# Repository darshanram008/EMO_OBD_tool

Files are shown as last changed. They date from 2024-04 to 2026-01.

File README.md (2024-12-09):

# On board diagnostic tool: developed for EMO energy pvt ltd. 
## On Board diagnostic tool is a simple PCB that can be interfaced with the internal battery management system that cannot be accessed during the maintence or diagnostics of the battery pack 

<!--Table  of contents
- [section 1](#section-1)
- [section 2](#section-2)-->

*The priamry functionn of the OBD tool:*
1. Communicate via controller area network (CAN) protocol to the battery and
request the BMS to send necessary data.
2. Communicate via the Universal serial asynchronous RX-TX protocol to the GUI
and deliver the data in human readable from.

*The following operations are implemenetd*
1. Request real time data containing cell voltages, pack voltage, pack current,
temperatures, error and faults from the BMS and transmit to the USB via UART
in the form of strings appended with certain identifiers.
2. Request the configuration parameters from the BMS that was already uploaded
upon getting a command request from the GUI
3. Push the new configuration parameters to the BMS on command request from the
GUI.
4. Request SD card data to be downloaded on request from the GUI.
5. Change baud rates of UART and CAN upon command request from GUI
6. Flow control between OBD and BMS whenever there is an event of exchanging
data.

## 
- Microcontroller unit: Microchip PIC18F27Q84
- CAN transciever: Microchip MCP2551; variable Baud rate upto 1Mbps
- UART to USB converter: Silicon labs CP2102; variable baud rate uptp 115200
- Micrchip MPLAB X IDE

<!-- > some block quote itseems -->

<!-- `this is where code comes` -->

----------------
<!--
[We can post any link if you want] (https://github.com/darshanram008/EMO_OBD_tool/edit/main/README.md)

![This is how the PCB looks](EMO_PCB_IMG.png)

This is a footnote, you press this it will take you to the footnote. [^1]
Note: Footnotes are always at the end of this file.
## SECTION 1
> This is table

| Left side | Right side |
|---|---|
| 1. The advantage is good | 1. The advantage is bad |
| 2. The advantage is good | 2. The advantage is bad |
| 3. The advantage is good | 3. The advantage is bad |
| 4. The advantage is good | 4. The advantage is bad |

```
{
   \\This is fenced code 
  if (count == 0)
  {
  printf("Hello, zeros"):  
  }

}
```
## SECTION 2
> Definitions

UART
: Universal Asyncronous receiver and transmitter

CAN
: Controller area network

~~Strikeout anything~~

- [x] Task completed
- [x] Task completed
- [ ] Task Incomplete
- [ ] Task incomplete

There are emoji as well! :joy:

i have more :angry:

take more 📶

==Some very important points==.

to put subscript you can do this H<sub>2</sub>O

To put superscript do this X<sup>2</sup>Y

[^1]: This is the footnote, you can add any references you want.

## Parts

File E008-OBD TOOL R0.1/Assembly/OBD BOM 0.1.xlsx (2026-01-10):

Sl.No | Reference | Value | Footprint | Description | MPN | Manufacturer | Qty
1 | C1-C3, C9, C12 | 4.7uF/25V | Capacitor_SMD:C_0402_1005Metric | 402 | CC0402MRX5R7BB475 | YAGEO | 5
2 | C4 | 1uF/25V | Capacitor_SMD:C_0402_1005Metric | 402 | CC0402KPX5R7BB105 | YAGEO | 1
3 | C5 | 0.1n/25V | Capacitor_SMD:C_0402_1005Metric | 402 | CC0402KRX7R7BB101 | YAGEO | 1
4 | C6, C7 | 33p/25V | Capacitor_SMD:C_0402_1005Metric | 402 | CC0201JPNPO7BN330 | YAGEO | 2
5 | C8, C10, C11 | 0.1uF/25V | Capacitor_SMD:C_0402_1005Metric | 402 | CC0402KRX7R7BB104 | YAGEO | 3
6 | C13 | 0.001uF/25V | Capacitor_SMD:C_0402_1005Metric | 402 | CC0100KRX7R7BB102 | YAGEO | 1
7 | C14 | 0.01uF/25V | Capacitor_SMD:C_0402_1005Metric | 402 | CC0805JKNPO7BN103 | YAGEO | 1
8 | D1 | SP0505BAHT | Custommm:SP0505BAHT_SOT95P280X145-6N.kicad_mod |  | SP0505BAHTG |  | 1
9 | D2, D4 | LED | LED_THT:LED_D3.0mm_IRBlack | LED |  | bivar | 2
10 | D3 | LED | LED_SMD:LED_0603_1608Metric | LED |  | bivar | 1
11 | H1-H6 | MountingHole | MountingHole:MountingHole_2.2mm_M2 |  |  |  | 6
12 | J1 | samtec_03x02 | Custommm:SAMTEC_1.27mm_03x02 | DEBUG |  |  | 1
13 | J2 | I2C | Connector_PinHeader_1.27mm:PinHeader_1x04_P1.27mm_Vertical | 4 pin JST connector | 240-004 | Digilent | 1
14 | J4 | USB C 2.0 | Connector_USB:USB_C_Receptacle_HRO_TYPE-C-31-M-12 | USB C | USB4105-GF-A | GCT | 1
15 | J6 | CAN | Connector_JST:JST_GH_SM03B-GHS-TB_1x03-1MP_P1.25mm_Horizontal |  | SM03B-GHS-TB |  | 1
16 | JP1 | Jumper_2_Open | Jumper:SolderJumper-2_P1.3mm_Open_RoundedPad1.0x1.5mm |  |  |  | 1
17 | R1-R3, R5, R7, R20, R25, R26, R35 | 0R | Resistor_SMD:R_0603_1608Metric | 603 | RC0603FR-SNE96L | YAGEO | 9
18 | R4 | 120R | Resistor_SMD:R_0402_1005Metric | 402 | RC0402FR-07120RL | YAGEO | 1
19 | R6, R8, R12, R17, R22-R24 | 1k | Resistor_SMD:R_0402_1005Metric | 402 | RT0402BRE071KL | YAGEO | 7
20 | R9, R41, R42 | 330R | Resistor_SMD:R_0402_1005Metric | 402 | RC0402JR-7D330RL | YAGEO | 3
21 | R10 | 10k | Resistor_SMD:R_0402_1005Metric | 402 | RC0402FR-0710KL | YAGEO | 1
22 | R11 | 470R | Resistor_SMD:R_0402_1005Metric | 402 | RC0402FR-07470RL | YAGEO | 1
23 | R13, R14 | 5.1k | Resistor_SMD:R_0402_1005Metric | 402 | RC0402FR-075K1L | YAGEO | 2
24 | R15 | 0R | Resistor_SMD:R_0805_2012Metric | 603 | RC0603FR-SNE96L | YAGEO | 1
25 | R16 | 5A fuse | Custommm:FUSE | - | 0494.250NR | YAGEO | 1
26 | R18 | 22.1k | Resistor_SMD:R_0402_1005Metric | 402 | RC0402FR-1322K1L | YAGEO | 1
27 | R19 | 47.5k | Resistor_SMD:R_0402_1005Metric | 402 | RC0402FR-0747K5L | YAGEO | 1
28 | R21, R38-R40 | 10K | Resistor_SMD:R_0402_1005Metric | 402 | RC0402FR-0710KL | YAGEO | 4
29 | R27, R28 | 10R | Resistor_SMD:R_0603_1608Metric | 603 | RC0603FR-0710RL | YAGEO | 2
30 | R29-R34, R36, R37 | 1k | Resistor_SMD:R_0603_1608Metric | 603 | RT0603WRE071KL | YAGEO | 8
31 | U1 | PIC18F27Q84 | Custommm:PIC18F27Q84_SOIC127P1030X265-28N | MCU | PIC18F27Q84-E/SO | Microchip Technology | 1
32 | U2 | MCP2551-I-P | mcp2551:SOIC127P600X175-8N | CAN IC | MCP2551-I/SN | Microchip Technology | 1
33 | U3 | CP2102-GMR | Custommm:QFN50P500X500X100-29N-D | UART to USB | 634-CP2102-GMR |  | 1
34 | U4 | AT24C256C-SSHL-T | Custommm:AT24C256_SOIC127P600X175-8N | EEPROM | AT24C256C-SSHL-T |  | 1
35 | Y2 | 10MHz | Custommm:ABLS8000MHZB4T | CRYSTAL | ABM7-10.000MHZ-D2Y-T | ABRACON | 1

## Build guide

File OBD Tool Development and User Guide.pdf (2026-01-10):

## OBD Tool Development and User Guide

## August 2023

The following document summarises the initiation and development of a general On-Board diagnostic tool over the course of Feb 2023 to August 2023 for all the battery packs and energy storage systems developed by EMO energy Pvt. ltd.

INTRODUCTION

The On-Board diagnostic tool is the mediator between the graphical user interface (GUI) and the battery management system (BMS) allowing data to be communicated seamlessly by converting data from BMS readable format to human readable format and vice versa.

The primary functions of the OBD tool are as follows
1. Communicate via controller area network (CAN) protocol to the battery and request the BMS to send necessary data.
2. Communicate via the Universal serial asynchronous RX-TX protocol to the GUI and deliver the data in human readable from.

At present the following functions have been implemented:

1. Request real time data containing cell voltages, pack voltage, pack current, temperatures, error and faults from the BMS and transmit to the USB via UART in the form of strings appended with certain identifiers.
2. Request the configuration parameters from the BMS that was already uploaded upon getting a command request from the GUI
3. Push the new configuration parameters to the BMS on command request from the GUI.
4. Request SD card data to be downloaded on request from the GUI.
5. Change baud rates of UART and CAN upon command request from GUI
6. Flow control between OBD and BMS whenever there is an event of exchanging data.

## CHAPTER 1

## HARDWARE DESIGN

1. The PCB for the OBD tool is designed in KICAD
2. PIC18F27Q84 is used as the MCU on the PCB (Note: The available curiosity nano development board has PIC18F57Q84 as its MCU)
3. CP2102-GMR QFN29 is used for UART to USB converter, MCP2551 is used as CAN controller.
4. USB C is used for connecting it to the device running GUI, and a 3 pin JST connector is used for connecting to the BMS.
5. A 10MHz crystal is used for as external clock for the PIC.

Further schematics and layout can be found in the KICAD project.

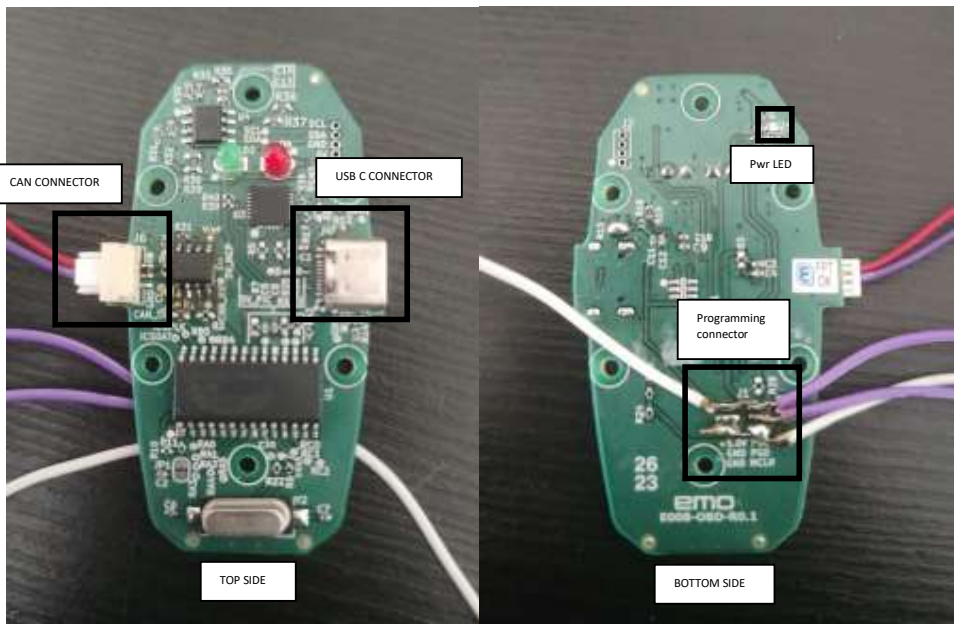
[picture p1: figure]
CAN CONNECTOR; USB C CONNECTOR; Programming connector; Pwr LED; TOP SIDE; BOTTOM SIDE

## CHAPTER 2

## FIRMWARE DEVELOPMENT

The OBD is made sure to be useable only when the GUI is opened on the host computer as a result a simple state machine consisting of two states is implemented.

- “GUI_connected” state
- “GUI_disconnected” state
1. GUI_disconnected state

This state is when the OBD is powered and the GUI application is not opened on the host computer.

- The OBD sends command “AT+TEST\r\n” continuously on the UART until it receives command “AT+TEST+OK\r\n”
- During disconnected state any normal operation or sending commands through foreign serial terminal is prohibited, unless it is a “AT+TEST=OK\r\n” command which is a breach of security.
- Upon reading “AT+TEST=OK\r\n” the OBD switches to the next state.
2. GUI_connected state

This state is when the OBD is powered and the GUI application is running on the host computer

- There are 10 events that the OBD might go into during this state
- Default_event: To continuously request BMS the data containing pack voltage, pack current, SOC and error codes followed by 20 cell voltages and 6 thermistor values. The data is appended to three strings. First containing error codes, pack voltage, pack current and SOC with “VCS” as identifiers, Second containing the 20 cell voltages with “#*” as identifiers, third containing 6 thermistor values with “^C” as identifier. All three strings are sent over UART continuously as comma separated values.
CAN ID for request: 0x1806F4F4
CAN DATA for request: {0x04, 0x0D, 0x04, 0x63}
- BMS_baud_rate_change_event & GUI_baud_rate_change_event: Request to change the baud rates/ bit rates of the CAN for the BMS or the UART for the GUI.
The request to change the baud rate is initiated by the GUI through the following commands
For UART:
1. “AT+BAUD=1\r\n”: Changes UART baud rate to 9600 (default) when OBD is powered or reset.
2. “AT+BAUD=2\r\n”: Changes UART baud rate to 57600
3. “AT+BAUD=3”: Changes UART baud rate to 115200

For CAN:

1. “AT+CANB=1\r\n”: Changes CAN bit rate to 125Kbps
2. “AT+CANB=2\r\n”: Changes CAN bit rate to 250Kbps
3. “AT+CANB=3\r\n”: Changes CAN bit rate to 500Kbps

Note: The default CAN bit rate when OBD is powered will go to 250Kbps, however when changed by the GUI the OBD will register the new bit rate to its EEPROM. Upon changing the bit rate of the OBD a message is also sent to the BMS on the older baud rate to change its bit rate to the new bit rate that OBD has been asked to set to.

CAN ID for 125Kbps: 0x1806F4F4; CAN DATA: {0x04, 0x0D, 0x04, 0x66}

CAN ID for 250Kbps: 0x1806F4F4; CAN DATA: {0x04, 0x0D, 0x04, 0x65}

CAN ID for 500Kbps: 0x1806F4F4; CAN DATA: {0x04, 0x0D, 0x04, 0x64}

- sd_data_download_event: Request to download the SD card data from given set of from date and to date. The request to download the SD card data from the BMS is
initiated | by | the | GUI | with | the | command:
“AT+DATA=1,DD,MM,YY,DD,MM,YY\r\n” (from date followed by To date) or “AT+DATA=2\r\n” if the entire SD card data has to be downloaded.
On receiving the command, the dates are segregated and stored in an 8byte array, the first two bytes will contain the character ‘S’ and ‘D’ the remaining 6 bytes will contain the DD MM YY DD MM YY.
CAN ID for DATE download: 0x1806F4F4; CAN DATA: {‘S’, ‘D’, DD,MM,YY,DD,MM,YY}
CAN ID for FULL download: 0x1806F4F4; CAN DATA: {‘S’, ‘D’, 0xFF, 0xFF, 0x00, 0x00, 0x00, 0x00}

Flow control for exchanging SD card data:

The flow control is written in such a way that after exchanging 48bytes (1 packet) between the OBD and the BMS, it is sent to the GUI with “SD” as identifiers with every byte as comma separated values.

1 packet (48bytes) consists of 7 CAN frames/messages with ID: 0x0121FFF4
Frame 1: {0x10,D1,D2,D3,D4,D5,D6,D7}
D1: contains the number of bytes in a packet, for examples if first packet has 48bytes D1 would be 48, if last pack has just 46bytes then D1 would be 46 and so on.
Frame 2: {0x20,D1,D2,D3,D4,D5,D6,D7}
Frame 3: {0x21,D1,D2,D3,D4,D5,D6,D7}
Frame 4: {0x22,D1,D2,D3,D4,D5,D6,D7}
Frame 5: {0x23,D1,D2,D3,D4,D5,D6,D7} Frame 6: {0x24,D1,D2,D3,D4,D5,D6,D7}
Frame 7: {0x25,D1,D2,D3,D4,D5,D6,D7}

Upon sending the request for downloading SD card data to the BMS, the BMS responds with the Frame 1, then OBD responds back with an acknowledgement
message | with | ID | 0x1806F4F6 | and | data
{0x01,0x00,0x00,0x00,0x00,0x00,0x00,0x00} it then starts its timer and waits for the next frame, if the BMS does not respond within 6sec (set by the timer) OBD transmits a timeout message to both BMS and GUI and goes back to the default event.

BMS timeout message: ID: 0x1806F4F6 data: {0xFF,0xFF,0x00,0x00,0x00,0x00,0x00,0x00}
GUI timeout message: “AT+TIME\r\n”

If the BMS responds within 6 seconds the OBD continues to wait for subsequent frames and after the reception of all the 7 frames (48bytes) (1 packet), the BMS sends
a | confirmation | message | on | the | ID: | 0x0110FFF4 | with | the | data
{0x01,0x00,0x00,0x00,0x00,0x00,0x00,0x00}. and the OBD sends the received packet to the GUI as a CSV string with “SD” appended on it. The BMS Upon sending all the packets of the SD card data sends a “complete” message on the ID: 0x0110FFF4 with data: {0x02,0x00,0x00,0x00,0x00,0x00,0x00,0x00}. And the OBD sends the last packet to the GUI followed by a confirmation message “AT+DONE\r\n”.
- BMS_software_rst_event:

The request for resetting the BMS is initiated by the GUI with the command “AT+REST=1\r\n”

Upon receiving the command the OBD forwards the command request to the BMS through the ID:0x1806F4F5 with the message {0x00,0xFF,0x01,0x00}. The BMS if reset sends a confirmation message to the OBD on the ID: 0x0110FFF4 with the message{0x01,0x00,0x00,0x00,0x00,0x00,0x00}
The OBD on receiving this command sends a confirmation message to the GUI
“AT+DONE\r\n” | indicating | the | successful | resetting | of | the | BMS.
If the BMS fails to respond with the confirmation message within 6 sec (set by the timer) the OBD sends a timeout message to BMS and GUI and goes back to its default event.
BMS timeout message: ID: 0x1806F4F6 data: {0xFF,0xFF,0x00,0x00,0x00,0x00,0x00,0x00}
GUI timeout message: “AT+TIME\r\n”
- BMS_upl_config_event:

The process for uploading the new configuration parameters to the BMS is initiated by the GUI with the command “AT+CONF=1,xxxx,xxxx,xxxx,xxxx,xxxx,xxxx,xxxx,xx,xx,xx,xx,xx,xx,xx,xx\r\n” Where x represents digits, currently 15 parameters have been finalised. The parameters that contain 2 bytes of data has to be put in place of 4 digits and the parameters containing 1 byte data has to be put in place of 2 digits.
It is important to note that the parameters have to be sent in the form of 4 or 2 digits as OBD string processing is strictly based on the length of the string.
Since there are 15 parameters in total, 7 parameters with 2 bytes (4 digit) 8 parameters with 1 byte(2digit) there are totally 22 bytes of data to be transmitted to BMS.
The transmission is on the ID: 0x1806F4F5 with frames as follows.

Frame 1: {0x01, LSB1,MSB1,LSB2,MSB2,LSB3,MSB3,1

st two-digit }
Frame 2: {0x02, LSB4,MSB4,LSB5,MSB5,LSB6,MSB6,2

nd two-digit]}
Frame 3: {0x03, LSB7,MSB7, 3

rd two-digit,4

th two-digit ,5

th two-digit ,6

th
two-digit }
Frame 4: {0x04, 7

th two-digit, 8

th two-digit,0x00,0x00,0x00,0x00,0x00]} After each frame transmitted, the OBD waits for a confirmation message from the
BMS | that | comes | on | the | ID: | 0x0110FFF4 | with | the | data
{0x01,0x00,0x00,0x00,0x00,0x00,0x00,0x00}, if the confirmation is not received by the OBD within 6 seconds (set by the timer) it simply sends a timeout message to BMS and GUI and goes back to the default event.
BMS timeout message: ID: 0x1806F4F6 data: {0xFF,0xFF,0x00,0x00,0x00,0x00,0x00,0x00}
GUI timeout message: “AT+TIME\r\n”

After the last frame has been sent and confirmed by the BMS, the OBD sends a confirmation message to the GUI “AT+DONE\r\n”

- BMS_get_config_event:

The request to get the present configuration parameters from the BMS is initiated by the GUI with the command “AT+CONF=2\r\n”

The OBD upon receiving the command sends a request message to the BMS with the ID: 0x1806F4F5 and data: {0x00,0x01,0x00,0x00} and waits for the BMS to respond with a CAN message containing the ID:0x0121FFF5 and the following frames
Frame1: {0x01,LSB1,MSB1,LSB2,MSB2,LSB3,MSB3,1
| | | | | | st two-digit}
Frame2: {0x02,LSB4,MSB4,LSB5,MSB5,LSB6,MSB6,2

nd two-digit}
Frame3: {0x03,LSB7,MSB7,3

rd two-digit,4

th two-digit,5

th two-digit,6

th two-digit,7

| | | | | | | | | th two-
digit}
Frame4: {0x04,8

th two-digit,0x00,0x00,0x00,0x00,0x00,0x00}

After every frame is received from the BMS the OBD sends a confirmation on the ID: 0x1806F4F6 with the data: {0x01,0x00,0x00,0x00,0x00,0x00,0x00,0x00} and waits for the next frames to receive, if the time elapsed in waiting exceeds 6sec the OBD sends a timeout message to BMS and GUI and then goes back to the default event.

After the last frame has been sent by the BMS it sends a “complete” message on the ID: “0x0110FFF4” with the data {0x02,0x00,0x00,0x00,0x00,0x00,0x00,0x00}, After which the OBD sends the parameters to GUI as CSV string with “CON” as identifiers.

- BMS_bootloader_event:

Refer the following excel for the detailed CAN messages. CAN data - Google Sheets (https://docs.google.com/spreadsheets/d/1CL77GdZRY7Kqr-tseltxFlh5MpObE5scavTE46g4DnU/edit#gid=0)

## CHAPTER 3

## MPLAB CODE CONFIGURATION

The entire firmware is developed in MPLAB X IDE v6.10.

The projects titled OBD_CAN_UART is written for curiosity nano board carrying PIC18F57Q84 MCU, and the project titled OBD_TOO_PCB_FINAL is written for the E008-PCB carrying PIC18F27Q84 MCU.

The steps to configure projects for the development is as shown:

1. Create a new project from the file section, select standalone project and click next, choose the device as PIC18F27Q84 and click next, select xc8 compiler and give the project name and click finish.

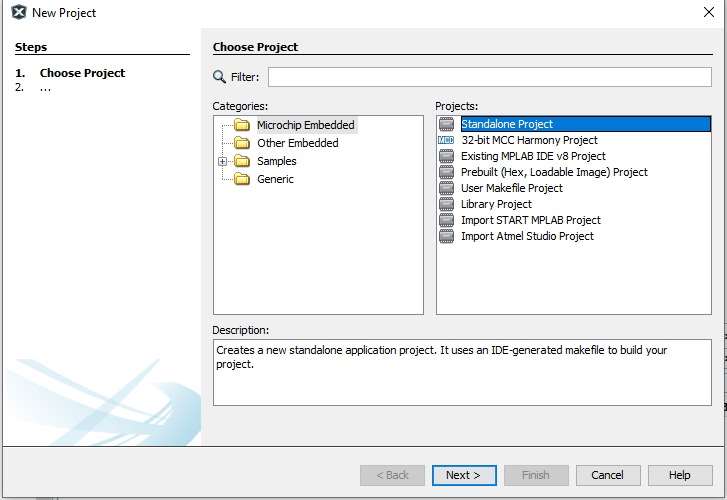
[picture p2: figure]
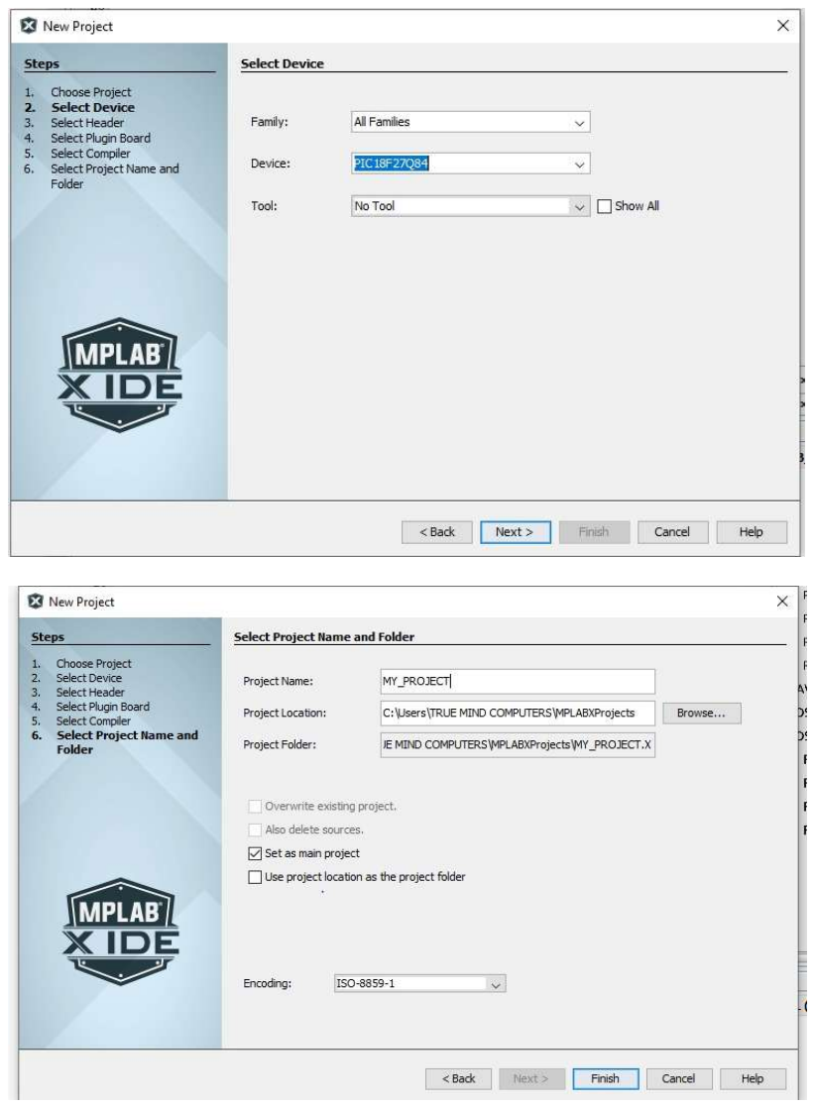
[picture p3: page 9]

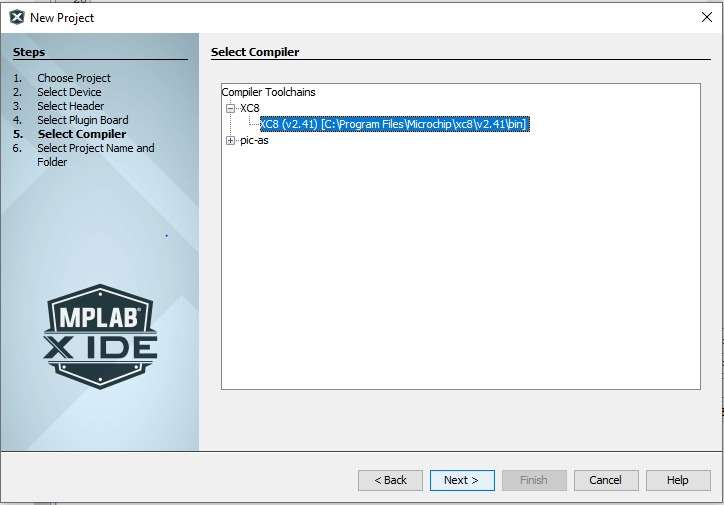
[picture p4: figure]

2. Open the MPLAB code configurator by clicking the blue logo called the MCC from the main page.

3. Select MCC classic.

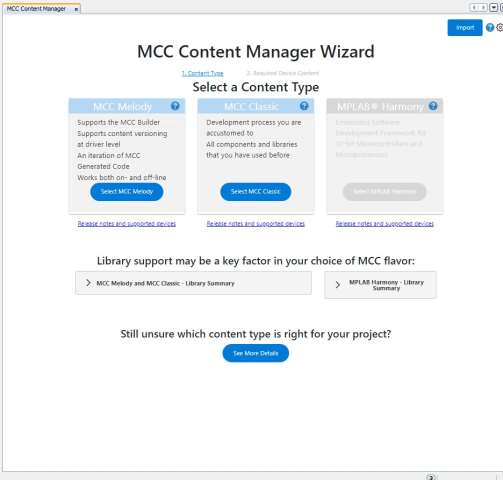
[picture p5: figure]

4. After downloading necessary modules click on finish

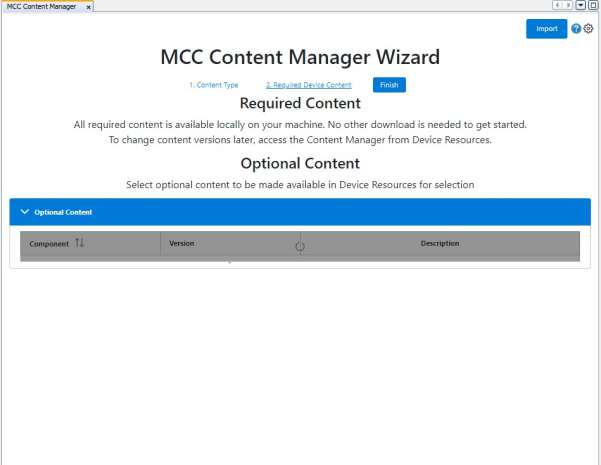
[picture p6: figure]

5. In the peripherals section click on plus to add the following peripherals UART2, CAN1, TIMER0, TIMER2, MEMORY

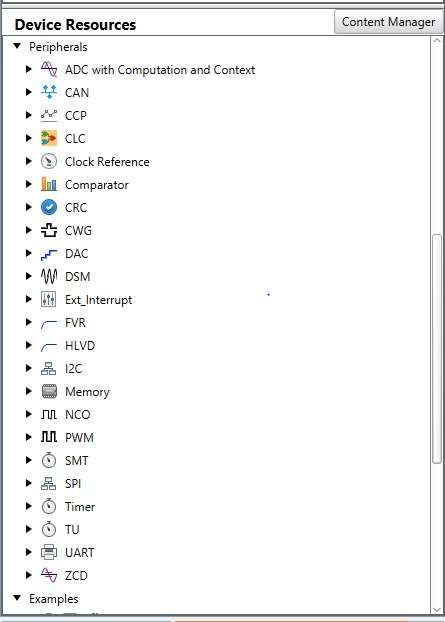
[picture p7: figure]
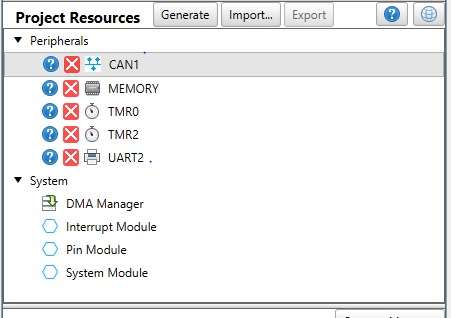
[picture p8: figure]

6. In the system module tab configure the following

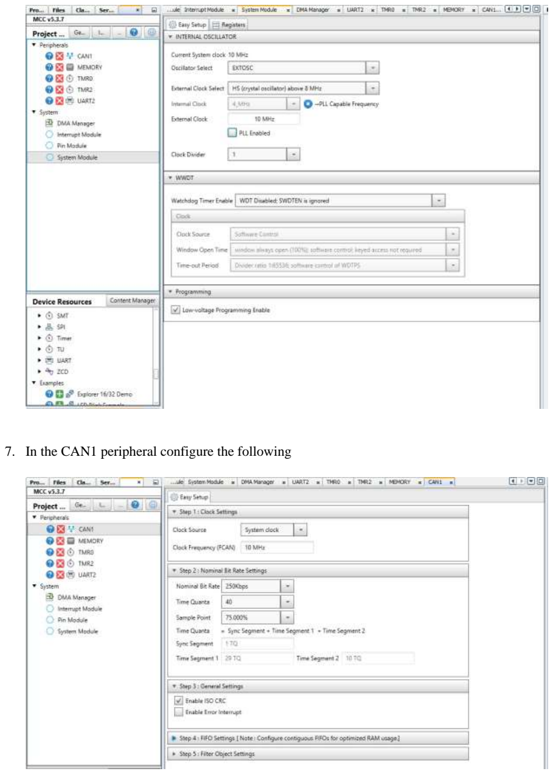
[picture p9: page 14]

7. In the CAN1 peripheral configure the following

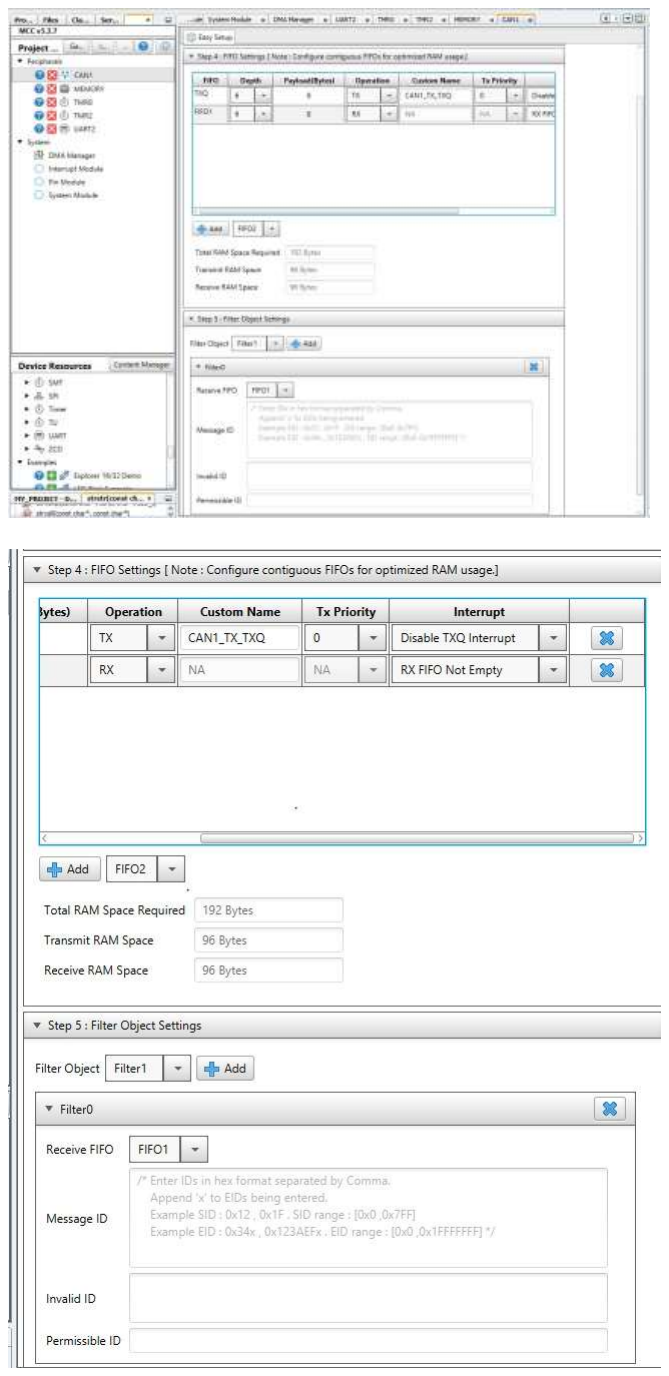
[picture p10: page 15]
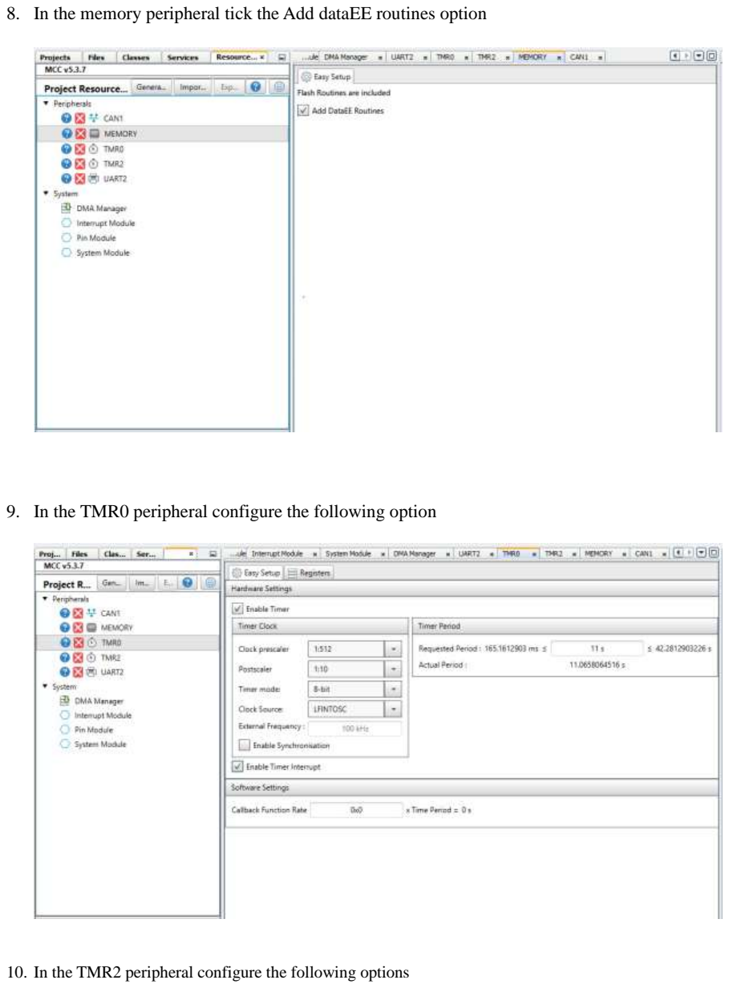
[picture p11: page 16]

8. In the memory peripheral tick the Add dataEE routines option
9. In the TMR0 peripheral configure the following option
10. In the TMR2 peripheral configure the following options

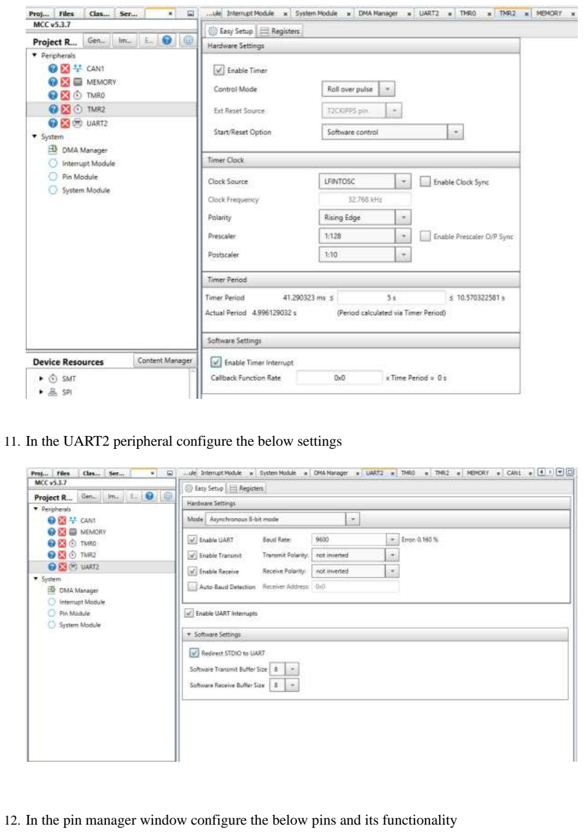
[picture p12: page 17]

11. In the UART2 peripheral configure the below settings
12. In the pin manager window configure the below pins and its functionality

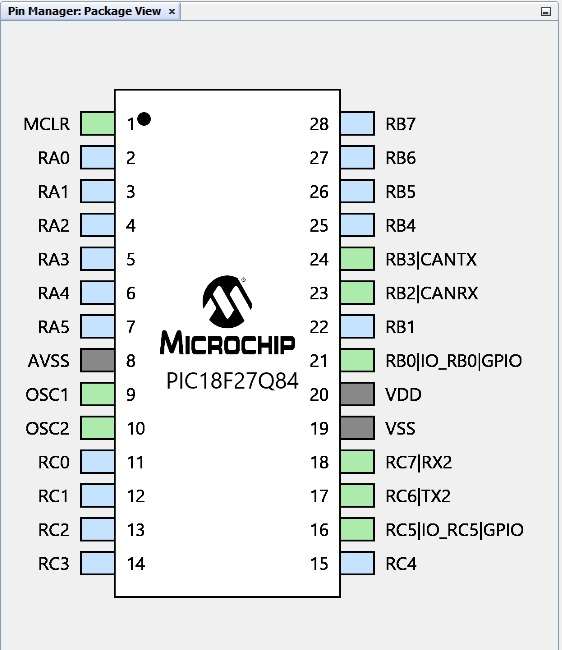
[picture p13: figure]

13. Make sure the following are enabled in interrupt module window

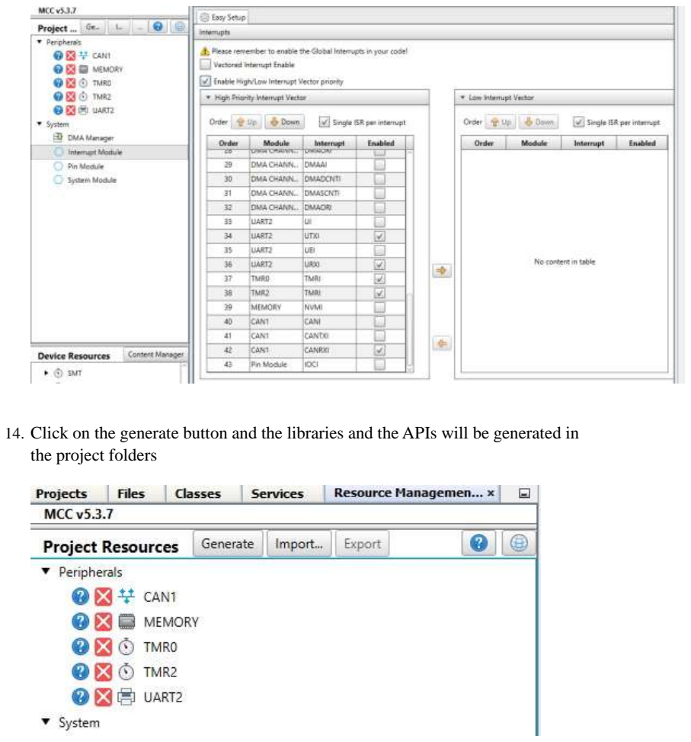
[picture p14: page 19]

14. Click on the generate button and the libraries and the APIs will be generated in the project folders

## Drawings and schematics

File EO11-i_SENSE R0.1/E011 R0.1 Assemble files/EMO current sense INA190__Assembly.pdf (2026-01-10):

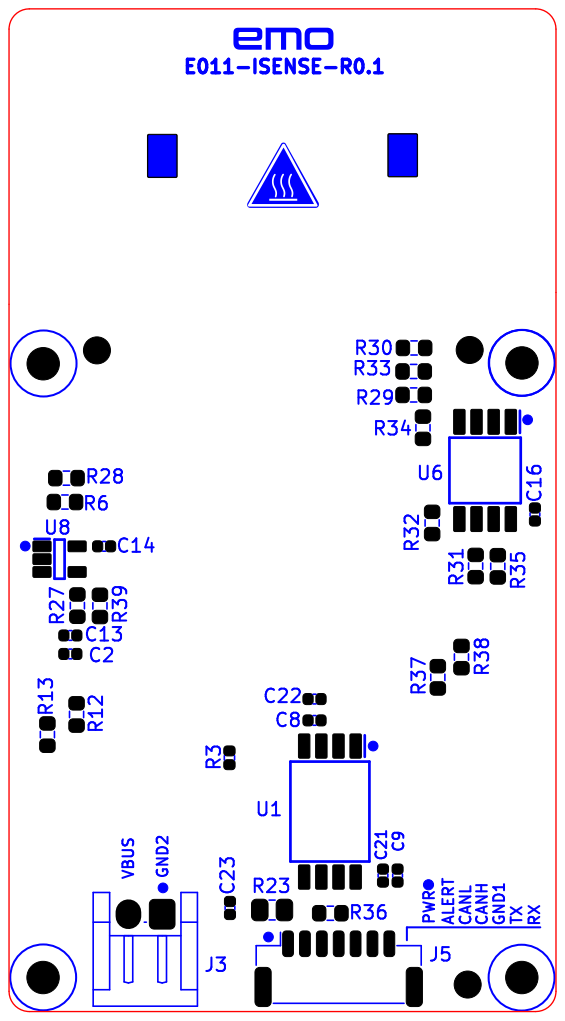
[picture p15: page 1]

GND2 TXRX E011-ISENSE-R0.1 VBUS PWR ALERT CANL CANH GND1 R13 C8 C16 R37R38 U6

J2 U2 CANL R¹⁶ | RA4C⁷ R⁷ U5 | C⁴

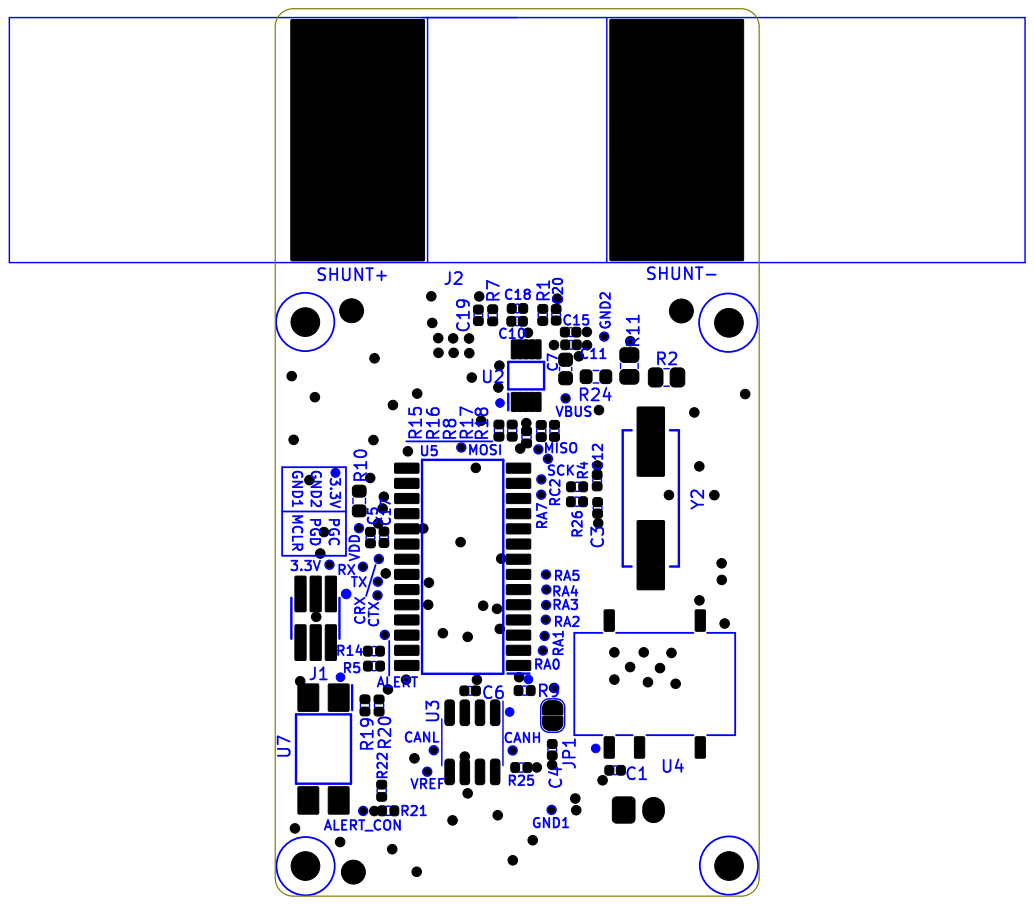
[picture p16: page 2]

GND1 3.3V SHUNT+ MCLR PGD PGC SHUNT- GND2 R20 R15 C5 R1 C20 VBUS R8

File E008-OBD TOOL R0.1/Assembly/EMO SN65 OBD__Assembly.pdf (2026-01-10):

C13 | U¹ CAN_RX | R36 U3 | SBU1 RA⁴ | R22 RA1 R1 | D2 | TX R¹⁷ cin
R4 | R¹⁶ RXR37 cout | J4 R29 | R³⁸

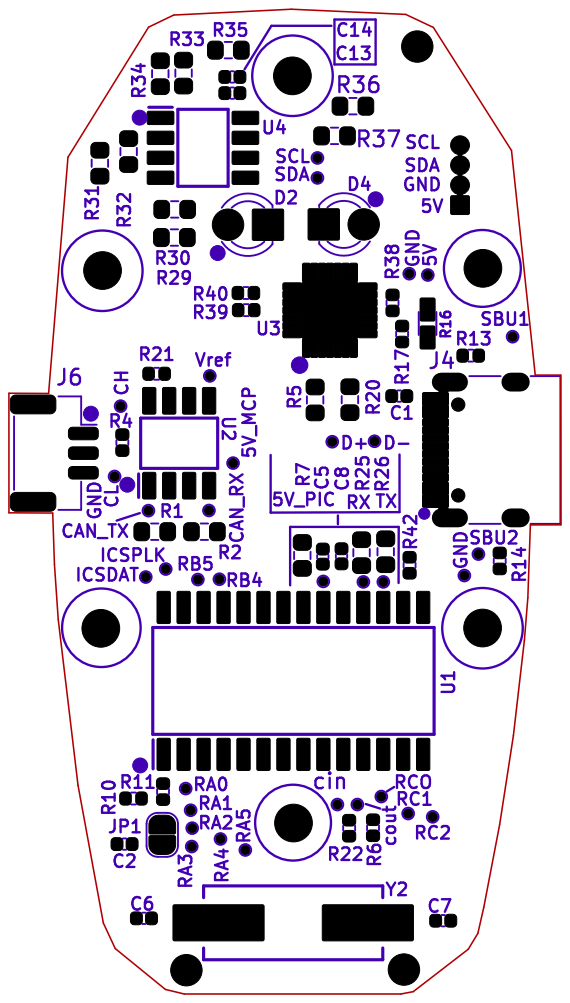
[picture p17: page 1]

+5.0V PGC GND PGD MCLR R²⁴ | C10 R²³ | R8 R⁴¹ | C3R12 J2 R¹⁹ E008-OBD-R0.1 | D³ C¹² | R²⁷ R³ R¹⁵ | R²⁸ C¹¹ | D1 R¹⁸ | J1 R⁹ C4 C9

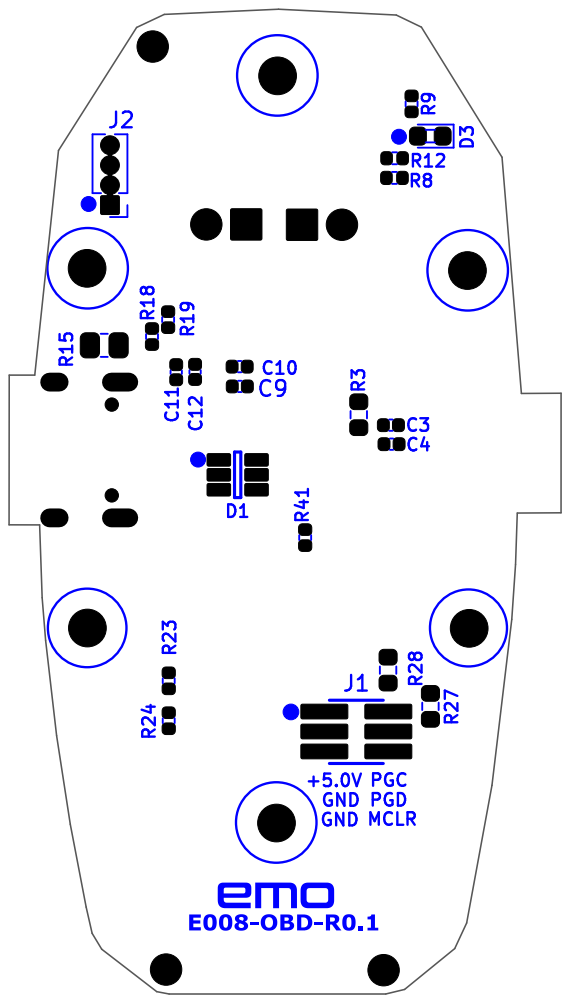
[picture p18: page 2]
GND

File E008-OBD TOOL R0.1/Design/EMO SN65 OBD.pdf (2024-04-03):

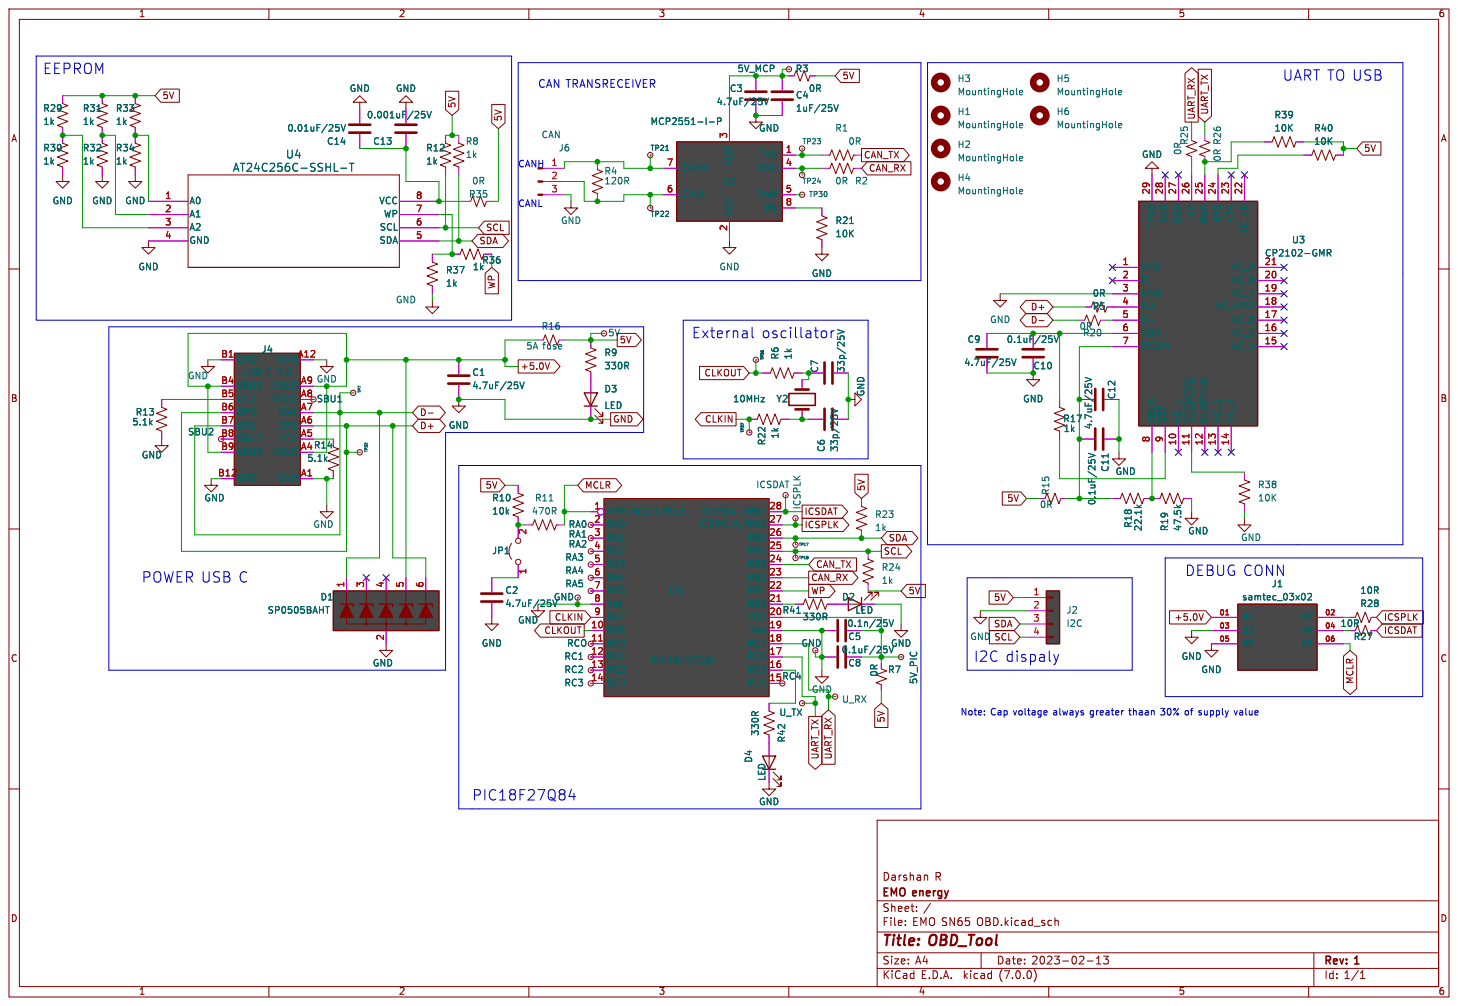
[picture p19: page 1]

3 RXD 4 Vref 5 CANL 6 CANH 7 Rs 8 U2 MCP2551-I-P

3 RXD 4 Vref 5 CANL 6 CANH 7 Rs 8

TP22 GNDA12 GND A1 VBUS A4 CC1 A5 DP1 A6 DN1 A7 SBU1 A8 VBUS A9 GND B1 GND B12 VBUS B4 CC2 B5 DP2 B6 DN2 B7 SBU2 B8 VBUS B9

Note: Cap voltage always greater thaan 30% of supply value

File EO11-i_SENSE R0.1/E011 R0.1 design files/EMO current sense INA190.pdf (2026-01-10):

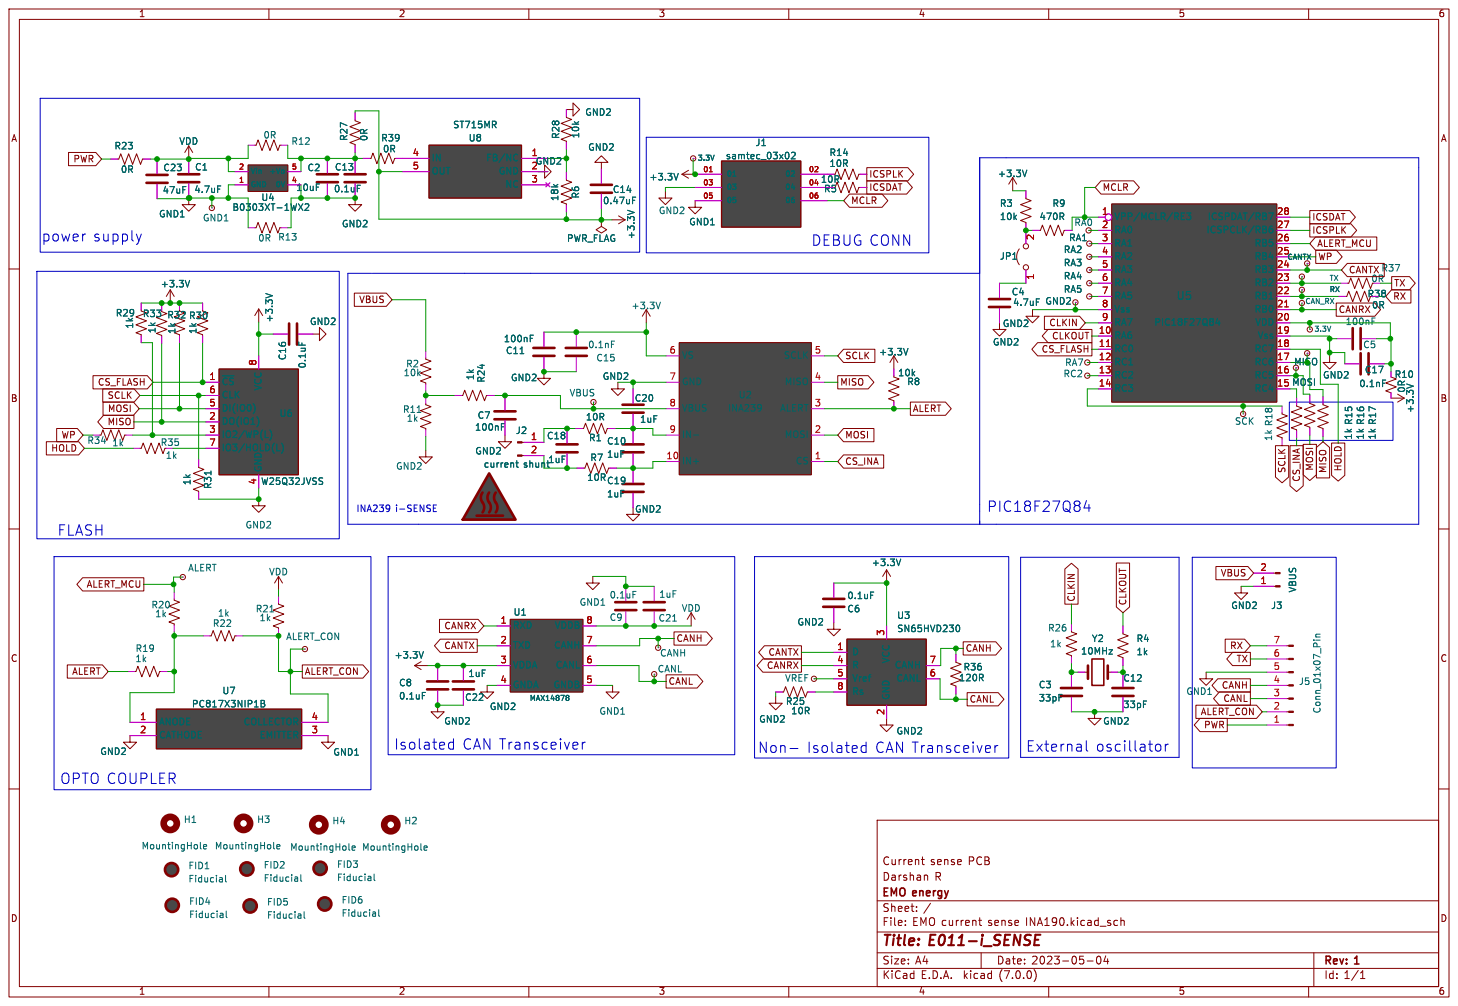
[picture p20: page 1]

Non- Isolated CAN Transceiver

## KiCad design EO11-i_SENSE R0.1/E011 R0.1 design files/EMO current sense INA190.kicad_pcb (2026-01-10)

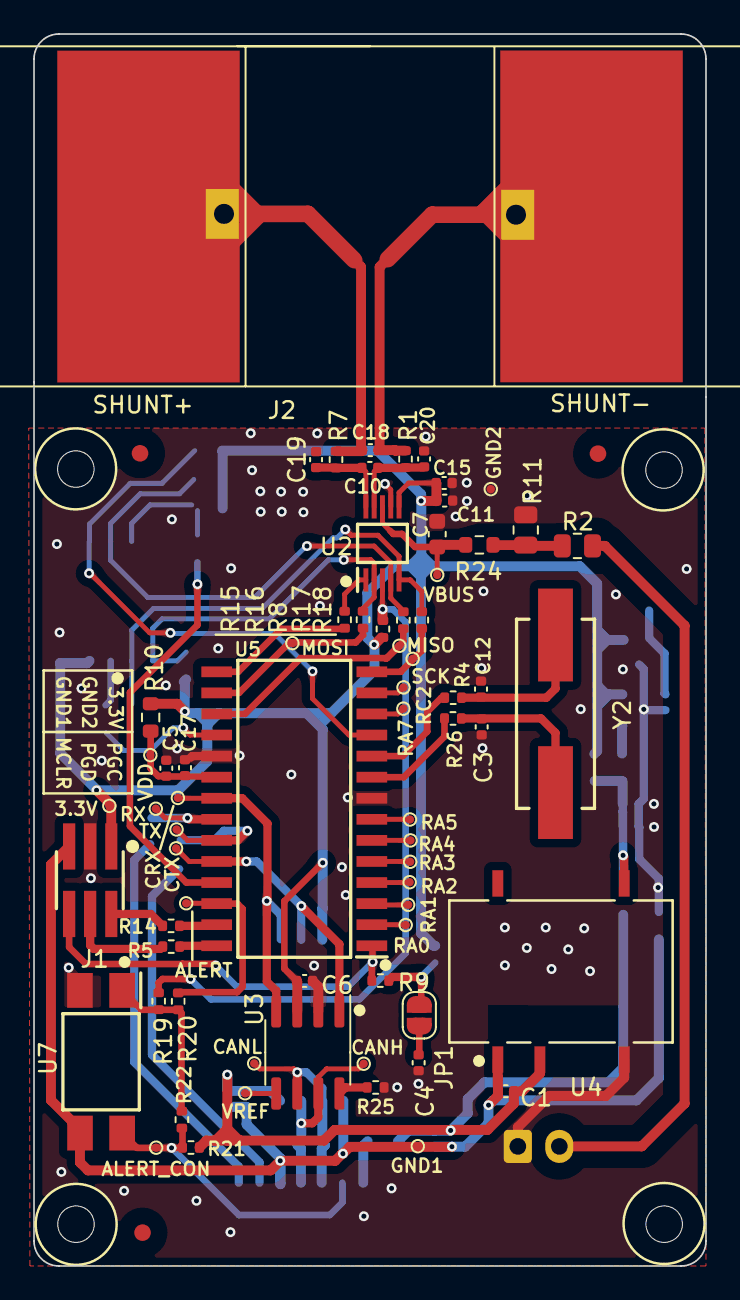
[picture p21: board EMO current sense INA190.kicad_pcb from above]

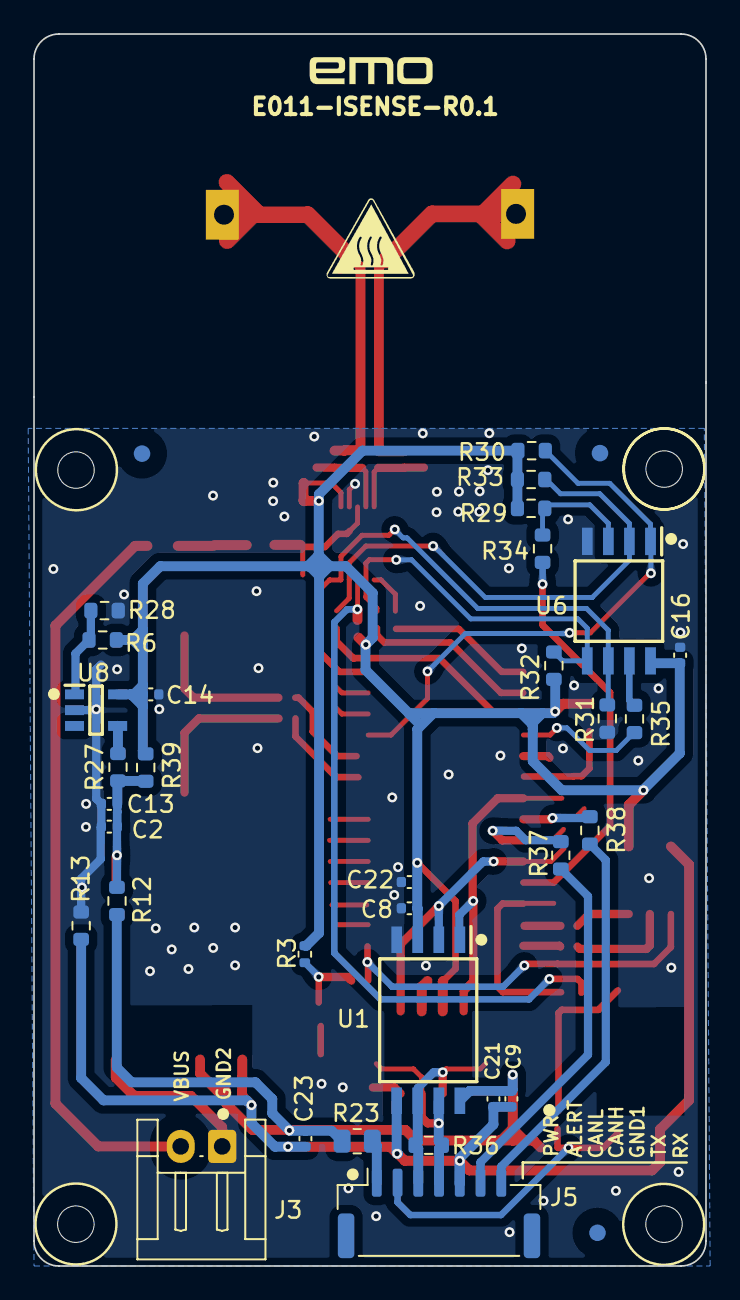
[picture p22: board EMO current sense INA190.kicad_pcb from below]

Board: 2 copper layers, 40.5 x 74.2 mm, 111 parts (35 on the bottom side), 62 nets.

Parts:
5V_PIC1: 3.3V; testpoint_0.5mm
C1, C4: 4.7uF; C_0402_1005Metric
C2: 10uF; C_0402_1005Metric
C3, C12: 33pF; C_0402_1005Metric
C5, C11: 100nF; C_0402_1005Metric
C6, C8, C9, C13, C16: 0.1uF; C_0402_1005Metric
C7: 100nF; C_0603_1608Metric
C10, C18, C19, C20, C21, C22: 1uF; C_0402_1005Metric
C14: 0.47uF; C_0402_1005Metric
C15, C17: 0.1nF; C_0402_1005Metric
C23: 47uF; C_0402_1005Metric
FID1, FID2, FID3, FID4, FID5, FID6: Fiducial; fiducial
H1, H2, H3, H4: MountingHole; MountingHole_2.2mm_M2
J1: samtec_03x02; SAMTEC_1.27mm_03x02
J2: current shunt; wsbs8518_shunt
J3: VBUS; JST_EH_S2B-EH_1x02_P2.50mm_Horizontal
J5: Conn_01x07_Pin; JST_GH_SM07B-GHS-TB_1x07-1MP_P1.25mm_Horizontal
JP1: Jumper_Open; SolderJumper-2_P1.3mm_Open_RoundedPad1.0x1.5mm
R1, R5, R7, R14, R25: 10R; R_0402_1005Metric
R2: 10k; R_0805_2012Metric
R3, R8: 10k; R_0402_1005Metric
R4, R15, R16, R17, R18, R19, R20, R21, R22, R26: 1k; R_0402_1005Metric
R6: 18k; R_0603_1608Metric
R9: 470R; R_0402_1005Metric
R10, R12, R13, R27, R37, R38, R39: 0R; R_0603_1608Metric
R11: 1k; R_0805_2012Metric
R23: 0R; R_0805_2012Metric
R24, R29, R30, R31, R32, R33, R34, R35: 1k; R_0603_1608Metric
R28: 10k; R_0603_1608Metric
R36: 120R; R_0603_1608Metric
TP1: ALERT_CON; testpoint_0.5mm
TP2: VBUS; testpoint_0.5mm
TP3: GND1; testpoint_0.5mm
TP4: CANH; testpoint_0.5mm
TP5: CANL; testpoint_0.5mm
TP6: MISO; testpoint_0.5mm
TP7: SCK; testpoint_0.5mm
TP8: MOSI; testpoint_0.5mm
TP9: GND2; testpoint_0.5mm
TP10: RA7; testpoint_0.5mm
TP11: RC2; testpoint_0.5mm
TP13: RA0; testpoint_0.5mm
TP14: RA1; testpoint_0.5mm
TP15: RA2; testpoint_0.5mm
TP16: RA3; testpoint_0.5mm
TP17: RA4; testpoint_0.5mm
TP18: RA5; testpoint_0.5mm
TP20: TX; testpoint_0.5mm
TP21: RX; testpoint_0.5mm
TP22: CRX; testpoint_0.5mm
TP23: CTX; testpoint_0.5mm
TP24: VDD; testpoint_0.5mm
TP25: ALERT; testpoint_0.5mm
TP27: VREF; testpoint_0.5mm
U1: MAX14878; MAX14878_SOIC127P1031X265-8N
U2: INA239; INA239_SOP50P490X110-10N
U3: SN65HVD230; SOIC-8_3.9x4.9mm_P1.27mm
U4: B0303XT-1WX2; B0303_B_XT-1WR2_MNS
U5: PIC18F27Q84; PIC18F27Q84_SOIC127P1030X265-28N
U6: W25Q32JVSS; W25Q32_SOIC127P790X216-8N
U7: PC817X3NIP1B; PC817X3_SOP254P960X420-4N
U8: ST715MR; ST715MR_SOT95P280X145-5N
Y2: 10MHz; ABLS8000MHZB4T

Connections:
+3.3V: 5V_PIC1.1, C6.2, C8.1, C11.2, C14.2, C15.2, C16.1, C22.2, J1.01, R3.1, R6.1, R8.1, R10.1, R27.2, R29.2, R30.2, R32.2, R33.2, U1.3 (VDDA), U2.6 (VS), U3.3 (VCC), U6.8 (VCC), U8.5 (OUT)
ALERT: R8.2, R19.1, U2.3 (ALERT)
ALERT_CON: J5.2, R21.1, R22.1, TP1.1, U7.4 (COLLECTOR)
ALERT_MCU: R20.2, TP25.1, U5.26 (RB5)
CANH: J5.4, R36.2, TP4.1, U1.7 (CANH), U3.7 (CANH)
CANL: J5.3, R36.1, TP5.1, U1.6 (CANL), U3.6 (CANL)
CANRX: TP22.1, U1.1 (RXD), U3.4 (R), U5.21 (RB0)
CANTX: TP23.1, U1.2 (TXD), U3.1 (D), U5.24 (RB3)
CLKIN: R26.1, U5.9 (RA7)
CLKOUT: R4.1, U5.10 (RA6)
CS_FLASH: R30.1, U5.11 (RC0), U6.1 (~CS)
CS_INA: R15.1, U2.1 (CS)
GND1: C1.2, C9.2, C21.2, C23.2, J1.05, J5.5, R13.2, TP3.1, U1.5 (GNDB), U4.1 (GND), U7.3 (EMITTER)
GND2: C2.2, C3.2, C4.2, C5.1, C6.1, C7.2, C8.2, C11.1, C12.2, C13.2, C14.1, C15.1, C16.2, C17.1, C19.2, C20.1, C22.1, J1.03, J3.1, R11.1, R13.1, R25.1, R28.2, R31.1, TP9.1, U1.4 (GNDA), U2.7 (GND), U3.2 (GND), U4.4 (0V), U5.8 (Vss), U5.19 (Vss), U6.4 (GND), U7.2 (CATHODE), U8.2 (GND)
HOLD: R35.2, U5.18 (RC7)
ICSDAT: R5.1, U5.28 (ICSPDAT/RB7)
ICSPLK: R14.1, U5.27 (ICSPCLK/RB6)
MCLR: J1.06, R9.2, U5.1 (VPP/MCLR/RE3)
MISO: R17.1, R33.1, U2.4 (MISO), U6.2 (DO(IO1))
MOSI: R16.1, R32.1, U2.2 (MOSI), U6.5 (DI(IO0))
unnamed: C3.1, R26.2, Y2.1
unnamed: C12.1, R4.2, Y2.2
unnamed: J1.02, R14.2
unnamed: J1.04, R5.2
unnamed: C18.1, J2.1, R1.1
unnamed: C18.2, J2.2, R7.1
unnamed: C4.1, JP1.1 (A)
unnamed: JP1.2 (B), R3.2, R9.1
unnamed: R2.1, R11.2, R24.1
unnamed: C10.2, C19.1, R7.2, U2.10 (IN+)
unnamed: C10.1, C20.2, R1.2, U2.9 (IN-)
unnamed: C7.1, R24.2, TP2.1, U2.8 (VBUS)
unnamed: R25.2, U3.8 (Rs)
unnamed: TP27.1, U3.5 (Vref)
unnamed: C2.1, C13.1, R12.1, R27.1, R39.2, U4.5 (+Vo)
unnamed: TP13.1, U5.2 (RA0)
unnamed: TP14.1, U5.3 (RA1)
unnamed: TP15.1, U5.4 (RA2)
unnamed: TP16.1, U5.5 (RA3)
unnamed: TP17.1, U5.6 (RA4)
unnamed: TP18.1, U5.7 (RA5)
unnamed: R38.1, TP21.1, U5.22 (RB1)
unnamed: R37.1, TP20.1, U5.23 (RB2)
unnamed: TP10.1, U5.12 (RC1)
unnamed: TP11.1, U5.13 (RC2)
unnamed: R18.2, TP7.1, U5.14 (RC3)
unnamed: R15.2, U5.15 (RC4)
unnamed: R16.2, TP8.1, U5.16 (RC5)
unnamed: R17.2, TP6.1, U5.17 (RC6)
unnamed: C5.2, C17.2, R10.2, TP24.1, U5.20 (VDD)
unnamed: R29.1, R34.1, U6.3 (IO2/WP(L))
unnamed: R35.1, U6.7 (IO3/HOLD(L))
unnamed: R19.2, R20.1, R22.2, U7.1 (ANODE)
unnamed: R6.2, R28.1, U8.1 (FB/NC)
unnamed: R39.1, U8.4 (IN)
PWR: J5.1, R23.2
RX: J5.7, R38.2
SCLK: R18.1, R31.2, U2.5 (SCLK), U6.6 (CLK)
TX: J5.6, R37.2
VBUS: J3.2, R2.2
VCC: C1.1, C9.1, C21.1, C23.1, R12.2, R21.2, R23.1, U1.8 (VDDB), U4.2 (Vin)
WP: R34.2, U5.25 (RB4)

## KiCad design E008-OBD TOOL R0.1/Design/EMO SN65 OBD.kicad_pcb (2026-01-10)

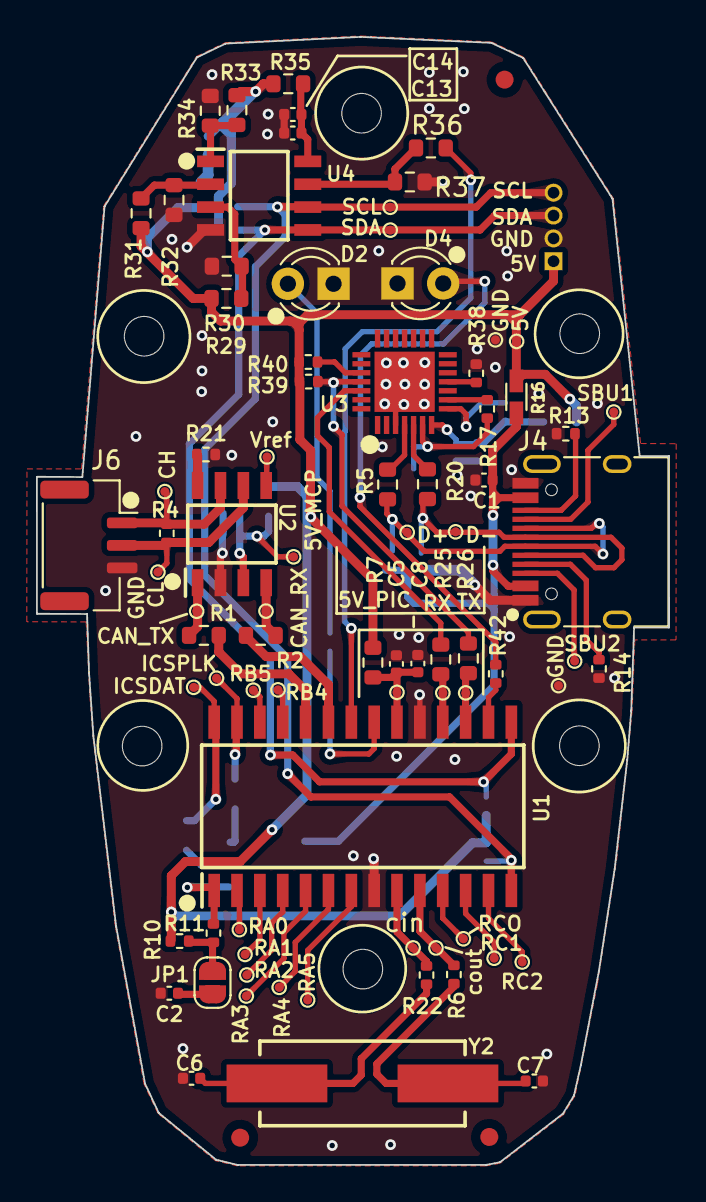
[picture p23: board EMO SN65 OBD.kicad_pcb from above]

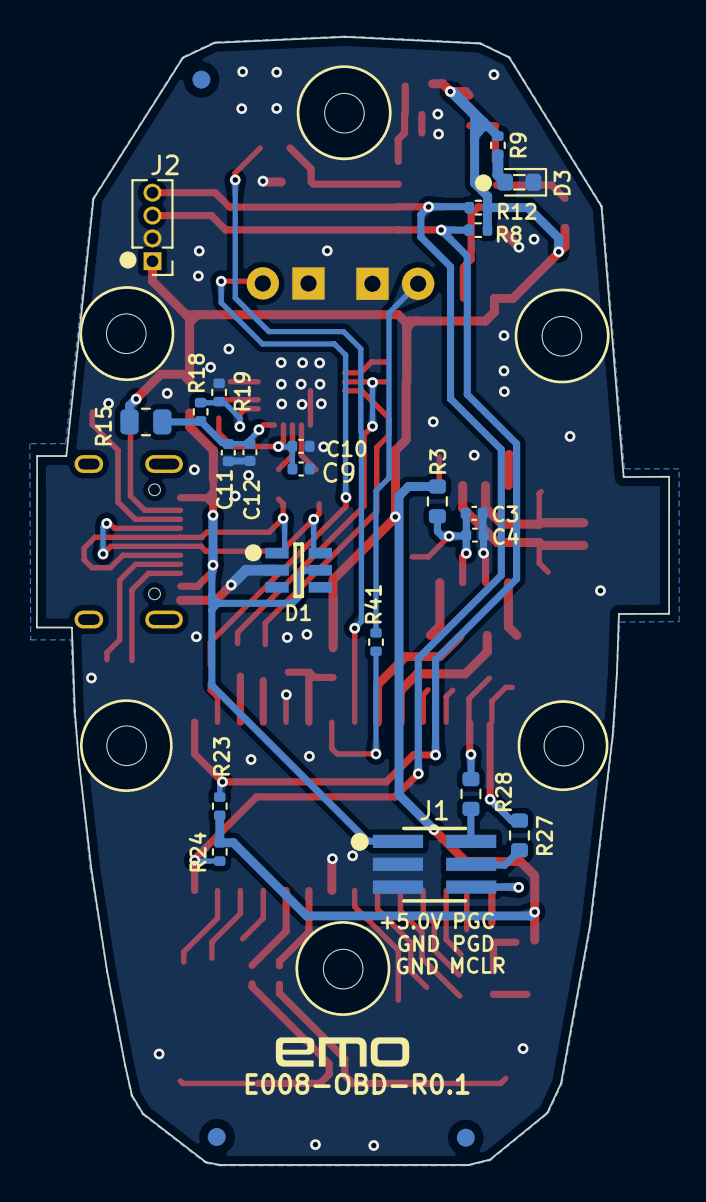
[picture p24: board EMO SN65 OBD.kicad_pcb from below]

Board: 2 copper layers, 35.1 x 62.7 mm, 109 parts (22 on the bottom side), 66 nets.

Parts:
C1, C2, C3, C9, C12: 4.7uF/25V; C_0402_1005Metric
C4: 1uF/25V; C_0402_1005Metric
C5: 0.1n/25V; C_0402_1005Metric
C6, C7: 33p/25V; C_0402_1005Metric
C8, C10, C11: 0.1uF/25V; C_0402_1005Metric
C13: 0.001uF/25V; C_0402_1005Metric
C14: 0.01uF/25V; C_0402_1005Metric
D1: SP0505BAHT; SP0505BAHT_SOT95P280X145-6N.kicad_mod
D2, D4: LED; LED_D3.0mm_IRBlack
D3: LED; LED_0603_1608Metric
H1, H2, H3, H4, H5, H6: MountingHole; MountingHole_2.2mm_M2
J1: samtec_03x02; SAMTEC_1.27mm_03x02
J2: I2C; PinHeader_1x04_P1.27mm_Vertical
J4: USB C 2.0; USB_C_Receptacle_HRO_TYPE-C-31-M-12
J6: CAN; JST_GH_SM03B-GHS-TB_1x03-1MP_P1.25mm_Horizontal
JP1: Jumper_2_Open; SolderJumper-2_P1.3mm_Open_RoundedPad1.0x1.5mm
R1, R2, R3, R5, R7, R20, R25, R26, R35: 0R; R_0603_1608Metric
R4: 120R; R_0402_1005Metric
R6, R8, R12, R17, R22, R23, R24: 1k; R_0402_1005Metric
R9, R41, R42: 330R; R_0402_1005Metric
R10: 10k; R_0402_1005Metric
R11: 470R; R_0402_1005Metric
R13, R14: 5.1k; R_0402_1005Metric
R15: 0R; R_0805_2012Metric
R16: 5A fuse; FUSE
R18: 22.1k; R_0402_1005Metric
R19: 47.5k; R_0402_1005Metric
R21, R38, R39, R40: 10K; R_0402_1005Metric
R27, R28: 10R; R_0603_1608Metric
R29, R30, R31, R32, R33, R34, R36, R37: 1k; R_0603_1608Metric
SBU2: SBU2; testpoint_0.5mm
TP1: RA0; testpoint_0.5mm
TP2: RA1; testpoint_0.5mm
TP3: RA2; testpoint_0.5mm
TP4: RA3; testpoint_0.5mm
TP5: RA4; testpoint_0.5mm
TP6: RA5; testpoint_0.5mm
TP7: D-; testpoint_0.5mm
TP8: RC1; testpoint_0.5mm
TP9: RC2; testpoint_0.5mm
TP10: RB5; testpoint_0.5mm
TP11: 5V; testpoint_0.5mm
TP12: RB4; testpoint_0.5mm
TP15: ICSPLK; testpoint_0.5mm
TP16: ICSDAT; testpoint_0.5mm
TP17: SDA; testpoint_0.5mm
TP18: SCL; testpoint_0.5mm
TP19: SBU1; testpoint_0.5mm
TP20, TP33: GND; testpoint_0.5mm
TP21: CH; testpoint_0.5mm
TP22: CL; testpoint_0.5mm
TP23: CAN_TX; testpoint_0.5mm
TP24: CAN_RX; testpoint_0.5mm
TP25: 5V_PIC; testpoint_0.5mm
TP26: cout; testpoint_0.5mm
TP27: cin; testpoint_0.5mm
TP29: 5V_MCP; testpoint_0.5mm
TP30: Vref; testpoint_0.5mm
TP31: RCO; testpoint_0.5mm
TP32: D+; testpoint_0.5mm
TP38: TX; testpoint_0.5mm
TP39: RX; testpoint_0.5mm
U1: PIC18F27Q84; PIC18F27Q84_SOIC127P1030X265-28N
U2: MCP2551-I-P; SOIC127P600X175-8N
U3: CP2102-GMR; QFN50P500X500X100-29N-D
U4: AT24C256C-SSHL-T; AT24C256_SOIC127P600X175-8N
Y2: 10MHz; ABLS8000MHZB4T

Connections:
5V: J2.1, R3.1, R7.1, R8.2, R9.1, R10.1, R12.2, R15.2, R16.1, R23.2, R24.2, R29.2, R31.2, R33.2, R35.1, R39.2, R40.2, TP11.1
+5.0V: C1.1, D1.5 (L4), J1.01, J4.A4 (VBUS), J4.A9 (VBUS), J4.B4 (VBUS), J4.B9 (VBUS), R16.2
CAN_RX: R2.2, U1.23 (RB2)
CAN_TX: R1.2, U1.24 (RB3)
CLKIN: R22.1, TP27.1, U1.9 (RA7)
CLKOUT: R6.1, TP26.1, U1.10 (RA6)
D+: D1.6 (L5), J4.A6 (DP1), J4.B6 (DP2), R5.2, TP32.1
D-: D1.1 (L1), J4.A7 (DN1), J4.B7 (DN2), R20.2, TP7.1
GND: C1.2, C2.2, C3.2, C4.2, C5.1, C6.2, C7.2, C8.1, C9.2, C10.1, C11.1, C12.1, C13.2, C14.2, D1.2 (VN), D2.1 (K), D3.1 (K), D4.1 (K), J1.03, J1.05, J2.2, J4.A1 (GND), J4.A12 (GND), J4.B1 (GND), J4.B12 (GND), J6.3, R13.2, R14.2, R19.2, R21.2, R30.1, R32.1, R34.1, R37.1, R38.2, TP20.1, TP33.1, U1.8 (Vss), U1.19 (Vss), U2.2 (VSS), U3.3 (GND), U3.29 (TPAD), U4.4 (GND)
ICSDAT: R27.1, TP16.1, U1.28 (ICSPDAT/RB7)
ICSPLK: R28.1, TP15.1, U1.27 (ICSPCLK/RB6)
MCLR: J1.06, R11.2, U1.1 (VPP/MCLR/RE3)
unnamed: C6.1, R22.2, Y2.1
unnamed: C7.1, R6.2, Y2.2
unnamed: D2.2 (A), R41.2
unnamed: D3.2 (A), R9.2
unnamed: D4.2 (A), R42.2
unnamed: J1.02, R28.2
unnamed: J1.04, R27.2
unnamed: J4.A5 (CC1), R14.1
unnamed: J4.B5 (CC2), R13.1
unnamed: J4.A8 (SBU1), TP19.1
unnamed: J4.B8 (SBU2), SBU2.1
unnamed: J6.1, R4.1, TP21.1, U2.7 (CANH)
unnamed: J6.2, R4.2, TP22.1, U2.6 (CANL)
unnamed: C2.1, JP1.1 (A)
unnamed: JP1.2 (B), R10.2, R11.1
unnamed: TP1.1, U1.2 (RA0)
unnamed: TP2.1, U1.3 (RA1)
unnamed: TP3.1, U1.4 (RA2)
unnamed: TP4.1, U1.5 (RA3)
unnamed: TP5.1, U1.6 (RA4)
unnamed: TP6.1, U1.7 (RA5)
unnamed: R41.1, U1.21 (RB0)
unnamed: TP12.1, U1.25 (RB4)
unnamed: TP10.1, U1.26 (RB5)
unnamed: TP31.1, U1.11 (RC0)
unnamed: TP8.1, U1.12 (RC1)
unnamed: TP9.1, U1.13 (RC2)
unnamed: R42.1, U1.16 (RC5)
unnamed: C5.2, C8.2, R7.2, TP25.1, U1.20 (VDD)
unnamed: R2.1, TP24.1, U2.4 (RXD)
unnamed: R21.1, U2.8 (Rs)
unnamed: R1.1, TP23.1, U2.1 (TXD)
unnamed: C3.1, C4.1, R3.2, TP29.1, U2.3 (VDD)
unnamed: TP30.1, U2.5 (Vref)
unnamed: R5.1, U3.4 (D+)
unnamed: R20.1, U3.5 (D-)
unnamed: C11.2, C12.2, R15.1, R18.1, U3.7 (REGIN)
unnamed: R40.1, U3.24 (RTS)
unnamed: R26.2, R39.1, U3.25 (RXD)
unnamed: R25.2, U3.26 (TXD)
unnamed: R18.2, R19.1, U3.8 (VBUS)
unnamed: C9.1, C10.2, R17.1, U3.6 (VDD)
unnamed: R17.2, U3.9 (~RST)
unnamed: R38.1, U3.11 (~SUSPEND)
unnamed: R33.1, R34.2, U4.1 (A0)
unnamed: R31.1, R32.2, U4.2 (A1)
unnamed: R29.1, R30.2, U4.3 (A2)
unnamed: C13.1, C14.1, R35.2, U4.8 (VCC)
unnamed: R36.2, R37.2, U4.7 (WP)
SCL: J2.4, R12.1, R24.1, TP18.1, U1.14 (RC3), U4.6 (SCL)
SDA: J2.3, R8.1, R23.1, TP17.1, U1.15 (RC4), U4.5 (SDA)
UART_RX: R25.1, TP39.1, U1.18 (RC7)
UART_TX: R26.1, TP38.1, U1.17 (RC6)
WP: R36.1, U1.22 (RB1)

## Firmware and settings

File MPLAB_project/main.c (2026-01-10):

/**
  Generated Main Source File

  Company:
    Microchip Technology Inc.

  File Name:
    main.c

  Summary:
    This is the main file generated using PIC10 / PIC12 / PIC16 / PIC18 MCUs

  Description:
    This header file provides implementations for driver APIs for all modules selected in the GUI.
    Generation Information :
        Product Revision  :  PIC10 / PIC12 / PIC16 / PIC18 MCUs - 1.81.8
        Device            :  PIC18F27Q84
        Driver Version    :  2.00
 */

/*
    (c) 2018 Microchip Technology Inc. and its subsidiaries. 
    
    Subject to your compliance with these terms, you may use Microchip software and any 
    derivatives exclusively with Microchip products. It is your responsibility to comply with third party 
    license terms applicable to your use of third party software (including open source software) that 
    may accompany Microchip software.
    
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
    IN NO EVENT WILL MICROCHIP BE LIABLE FOR ANY INDIRECT, SPECIAL, PUNITIVE, 
    INCIDENTAL OR CONSEQUENTIAL LOSS, DAMAGE, COST OR EXPENSE OF ANY KIND 
    WHATSOEVER RELATED TO THE SOFTWARE, HOWEVER CAUSED, EVEN IF MICROCHIP 
    HAS BEEN ADVISED OF THE POSSIBILITY OR THE DAMAGES ARE FORESEEABLE. TO 
    THE FULLEST EXTENT ALLOWED BY LAW, MICROCHIP'S TOTAL LIABILITY ON ALL 
    CLAIMS IN ANY WAY RELATED TO THIS SOFTWARE WILL NOT EXCEED THE AMOUNT 
    OF FEES, IF ANY, THAT YOU HAVE PAID DIRECTLY TO MICROCHIP FOR THIS 
    SOFTWARE.
 */

#include "mcc_generated_files/mcc.h"
#include "state_machine.h"
#include "pic18f27q84.h"
#include "BMS_data_handle.h"

char AT_command[8];
char command[150];

void main(void) {



    // baud_eeprom = DATAEE_ReadByte(0x00);
labelreset:
    GUI_baud_rate = 1;
    SYSTEM_Initialize();

    INTERRUPT_GlobalInterruptHighEnable();
    INTERRUPT_GlobalInterruptLowEnable();
   // UART2_SetRxInterruptHandler(UART2_Receive_ISR);
    // UART2_SetTxInterruptHandler(UART2_Write);
    for (int i = 0; i < 20; i++) {
        cell_voltage[i] = 0;
    }


    temperature1 = 0;
    temperature2 = 0;
    temperature3 = 0;
    temperature4 = 0;
    temperature5 = 0;
    temperature6 = 0;


    pack_voltage = 0;
    pack_current = 0;
    SOC = 0;
    err1 = 0;
    err2 = 0;
    err3 = 0;



    status1 = false;
    status2 = false;
    status3 = false;
    status4 = false;
    status5 = false;
    status6 = false;
    status7 = false;
    status8 = false;
    status9 = false;
    status10 = false;





    rx_receive_complete = false;




    for (int i = 0; i < 150; i++) {
        command[i] = '\0';
    }

    for (int i = 0; i < 8; i++) {
        AT_command[i] = '\0';
    }

    
    __delay_ms(5000);



     OBD_reset = false;
    state = GUI_disconnected;


    while (1) {

      

        current_state();

    }


    // Add your application code
}

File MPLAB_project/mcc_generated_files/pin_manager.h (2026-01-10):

/**
  @Generated Pin Manager Header File

  @Company:
    Microchip Technology Inc.

  @File Name:
    pin_manager.h

  @Summary:
    This is the Pin Manager file generated using PIC10 / PIC12 / PIC16 / PIC18 MCUs

  @Description
    This header file provides APIs for driver for .
    Generation Information :
        Product Revision  :  PIC10 / PIC12 / PIC16 / PIC18 MCUs - 1.81.8
        Device            :  PIC18F27Q84
        Driver Version    :  2.11
    The generated drivers are tested against the following:
        Compiler          :  XC8 2.36 and above
        MPLAB 	          :  MPLAB X 6.00	
*/

/*
    (c) 2018 Microchip Technology Inc. and its subsidiaries. 
    
    Subject to your compliance with these terms, you may use Microchip software and any 
    derivatives exclusively with Microchip products. It is your responsibility to comply with third party 
    license terms applicable to your use of third party software (including open source software) that 
    may accompany Microchip software.
    
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
    IN NO EVENT WILL MICROCHIP BE LIABLE FOR ANY INDIRECT, SPECIAL, PUNITIVE, 
    INCIDENTAL OR CONSEQUENTIAL LOSS, DAMAGE, COST OR EXPENSE OF ANY KIND 
    WHATSOEVER RELATED TO THE SOFTWARE, HOWEVER CAUSED, EVEN IF MICROCHIP 
    HAS BEEN ADVISED OF THE POSSIBILITY OR THE DAMAGES ARE FORESEEABLE. TO 
    THE FULLEST EXTENT ALLOWED BY LAW, MICROCHIP'S TOTAL LIABILITY ON ALL 
    CLAIMS IN ANY WAY RELATED TO THIS SOFTWARE WILL NOT EXCEED THE AMOUNT 
    OF FEES, IF ANY, THAT YOU HAVE PAID DIRECTLY TO MICROCHIP FOR THIS 
    SOFTWARE.
*/

#ifndef PIN_MANAGER_H
#define PIN_MANAGER_H

/**
  Section: Included Files
*/

#include <xc.h>

#define INPUT   1
#define OUTPUT  0

#define HIGH    1
#define LOW     0

#define ANALOG      1
#define DIGITAL     0

#define PULL_UP_ENABLED      1
#define PULL_UP_DISABLED     0

// get/set IO_RB0 aliases
#define IO_RB0_TRIS                 TRISBbits.TRISB0
#define IO_RB0_LAT                  LATBbits.LATB0
#define IO_RB0_PORT                 PORTBbits.RB0
#define IO_RB0_WPU                  WPUBbits.WPUB0
#define IO_RB0_OD                   ODCONBbits.ODCB0
#define IO_RB0_ANS                  ANSELBbits.ANSELB0
#define IO_RB0_SetHigh()            do { LATBbits.LATB0 = 1; } while(0)
#define IO_RB0_SetLow()             do { LATBbits.LATB0 = 0; } while(0)
#define IO_RB0_Toggle()             do { LATBbits.LATB0 = ~LATBbits.LATB0; } while(0)
#define IO_RB0_GetValue()           PORTBbits.RB0
#define IO_RB0_SetDigitalInput()    do { TRISBbits.TRISB0 = 1; } while(0)
#define IO_RB0_SetDigitalOutput()   do { TRISBbits.TRISB0 = 0; } while(0)
#define IO_RB0_SetPullup()          do { WPUBbits.WPUB0 = 1; } while(0)
#define IO_RB0_ResetPullup()        do { WPUBbits.WPUB0 = 0; } while(0)
#define IO_RB0_SetPushPull()        do { ODCONBbits.ODCB0 = 0; } while(0)
#define IO_RB0_SetOpenDrain()       do { ODCONBbits.ODCB0 = 1; } while(0)
#define IO_RB0_SetAnalogMode()      do { ANSELBbits.ANSELB0 = 1; } while(0)
#define IO_RB0_SetDigitalMode()     do { ANSELBbits.ANSELB0 = 0; } while(0)

// get/set RB2 procedures
#define RB2_SetHigh()            do { LATBbits.LATB2 = 1; } while(0)
#define RB2_SetLow()             do { LATBbits.LATB2 = 0; } while(0)
#define RB2_Toggle()             do { LATBbits.LATB2 = ~LATBbits.LATB2; } while(0)
#define RB2_GetValue()              PORTBbits.RB2
#define RB2_SetDigitalInput()    do { TRISBbits.TRISB2 = 1; } while(0)
#define RB2_SetDigitalOutput()   do { TRISBbits.TRISB2 = 0; } while(0)
#define RB2_SetPullup()             do { WPUBbits.WPUB2 = 1; } while(0)
#define RB2_ResetPullup()           do { WPUBbits.WPUB2 = 0; } while(0)
#define RB2_SetAnalogMode()         do { ANSELBbits.ANSELB2 = 1; } while(0)
#define RB2_SetDigitalMode()        do { ANSELBbits.ANSELB2 = 0; } while(0)

// get/set RB3 procedures
#define RB3_SetHigh()            do { LATBbits.LATB3 = 1; } while(0)
#define RB3_SetLow()             do { LATBbits.LATB3 = 0; } while(0)
#define RB3_Toggle()             do { LATBbits.LATB3 = ~LATBbits.LATB3; } while(0)
#define RB3_GetValue()              PORTBbits.RB3
#define RB3_SetDigitalInput()    do { TRISBbits.TRISB3 = 1; } while(0)
#define RB3_SetDigitalOutput()   do { TRISBbits.TRISB3 = 0; } while(0)
#define RB3_SetPullup()             do { WPUBbits.WPUB3 = 1; } while(0)
#define RB3_ResetPullup()           do { WPUBbits.WPUB3 = 0; } while(0)
#define RB3_SetAnalogMode()         do { ANSELBbits.ANSELB3 = 1; } while(0)
#define RB3_SetDigitalMode()        do { ANSELBbits.ANSELB3 = 0; } while(0)

// get/set IO_RC5 aliases
#define IO_RC5_TRIS                 TRISCbits.TRISC5
#define IO_RC5_LAT                  LATCbits.LATC5
#define IO_RC5_PORT                 PORTCbits.RC5
#define IO_RC5_WPU                  WPUCbits.WPUC5
#define IO_RC5_OD                   ODCONCbits.ODCC5
#define IO_RC5_ANS                  ANSELCbits.ANSELC5
#define IO_RC5_SetHigh()            do { LATCbits.LATC5 = 1; } while(0)
#define IO_RC5_SetLow()             do { LATCbits.LATC5 = 0; } while(0)
#define IO_RC5_Toggle()             do { LATCbits.LATC5 = ~LATCbits.LATC5; } while(0)
#define IO_RC5_GetValue()           PORTCbits.RC5
#define IO_RC5_SetDigitalInput()    do { TRISCbits.TRISC5 = 1; } while(0)
#define IO_RC5_SetDigitalOutput()   do { TRISCbits.TRISC5 = 0; } while(0)
#define IO_RC5_SetPullup()          do { WPUCbits.WPUC5 = 1; } while(0)
#define IO_RC5_ResetPullup()        do { WPUCbits.WPUC5 = 0; } while(0)
#define IO_RC5_SetPushPull()        do { ODCONCbits.ODCC5 = 0; } while(0)
#define IO_RC5_SetOpenDrain()       do { ODCONCbits.ODCC5 = 1; } while(0)
#define IO_RC5_SetAnalogMode()      do { ANSELCbits.ANSELC5 = 1; } while(0)
#define IO_RC5_SetDigitalMode()     do { ANSELCbits.ANSELC5 = 0; } while(0)

// get/set RC6 procedures
#define RC6_SetHigh()            do { LATCbits.LATC6 = 1; } while(0)
#define RC6_SetLow()             do { LATCbits.LATC6 = 0; } while(0)
#define RC6_Toggle()             do { LATCbits.LATC6 = ~LATCbits.LATC6; } while(0)
#define RC6_GetValue()              PORTCbits.RC6
#define RC6_SetDigitalInput()    do { TRISCbits.TRISC6 = 1; } while(0)
#define RC6_SetDigitalOutput()   do { TRISCbits.TRISC6 = 0; } while(0)
#define RC6_SetPullup()             do { WPUCbits.WPUC6 = 1; } while(0)
#define RC6_ResetPullup()           do { WPUCbits.WPUC6 = 0; } while(0)
#define RC6_SetAnalogMode()         do { ANSELCbits.ANSELC6 = 1; } while(0)
#define RC6_SetDigitalMode()        do { ANSELCbits.ANSELC6 = 0; } while(0)
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

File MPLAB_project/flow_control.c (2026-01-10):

#include "OBD_tool_events.h"
#include "flow_control.h"
#include "BMS_data_handle.h"


uint8_t can_ack[8] = {0x01, 0x00, 0x00, 0x00, 0x00, 0x00, 0x00, 0x00};
uint8_t sd_data[8], can_rx_sd_byte;
char timeout_msg[] = "AT+TIME\r\n", gui_ack[10] = "AT+DONE\r\n", AT_error[] = "AT+ERRR\r\n";
uint8_t  can_tx_conf[22], can_tx[8];
uint8_t can_sft_rst[4] = {0x00, 0xFF, 0x01, 0x00};
uint8_t can_config_req[4] = {0x00, 0x01, 0x00, 0x00};
uint8_t can_timeOut[8] = {0xFF, 0xFF, 0x00, 0x00, 0x00, 0x00, 0x00, 0x00};
bool timeout2 = false, timeout0= false;
 char transmit1[150], transmit2[150], transmit3[150], transmit4[80], transmit5[300]; 
void TMR2_DefaultInterruptHandler(void) {

    timeout2 = true;

}
void TMR0_DefaultInterruptHandler(void){
    
    timeout0 = true;
}

void B2G_config_data_flow() {


    /********pack and send first data********/
    can_tx[0] = 0x01;
    can_tx[1] = can_tx_conf[0];
    can_tx[2] = can_tx_conf[1];
    can_tx[3] = can_tx_conf[2];
    can_tx[4] = can_tx_conf[3];
    can_tx[5] = can_tx_conf[4];
    can_tx[6] = can_tx_conf[5];
    can_tx[7] = can_tx_conf[14];
    canTransmit(0x1806F4F5, 8U, can_tx);
    /*******wait for ok from BMS*/
    waitForNextCANMsg();
    /********************************/
    if ((status8 != true) || (can_data8[0] != 0x01)) {
        uart_transmit(timeout_msg);
        canTransmit(0x1806F4F6, 8U, can_timeOut);
        return;
    }

    /**********pack and send second data***/
    can_tx[0] = 0x02;
    can_tx[1] = can_tx_conf[6];
    can_tx[2] = can_tx_conf[7];
    can_tx[3] = can_tx_conf[8];
    can_tx[4] = can_tx_conf[9];
    can_tx[5] = can_tx_conf[10];
    can_tx[6] = can_tx_conf[11];
    can_tx[7] = can_tx_conf[15];
    canTransmit(0x1806F4F5, 8U, can_tx);
    status8 = false;
    can_rx_receive_flag = false;
    /*****wait for OK *******/
    waitForNextCANMsg();
    /***************************/
    if ((status8 != true) || (can_data8[0] != 0x01)) {
        uart_transmit(timeout_msg);
        canTransmit(0x1806F4F6, 8U, can_timeOut);
        return;
    }
    /**********pack and send third data***/
    can_tx[0] = 0x03;
    can_tx[1] = can_tx_conf[12];
    can_tx[2] = can_tx_conf[13];
    can_tx[3] = can_tx_conf[16];
    can_tx[4] = can_tx_conf[17];
    can_tx[5] = can_tx_conf[18];
    can_tx[6] = can_tx_conf[19];
    can_tx[7] = can_tx_conf[20];
    canTransmit(0x1806F4F5, 8U, can_tx);
    status8 = false;
    can_rx_receive_flag = false;
    /******wait for OK ********/
    waitForNextCANMsg();
    /********************************/
    if ((status8 != true) || (can_data8[0] != 0x01)) {
        uart_transmit(timeout_msg);
        canTransmit(0x1806F4F6, 8U, can_timeOut);
        return;
    }
    /*****pack and send fourth data***/
    can_tx[0] = 0x04;
    can_tx[1] = can_tx_conf[21];
    can_tx[2] = 0x00;
    can_tx[3] = 0x00;
    can_tx[4] = 0x00;
    can_tx[5] = 0x00;
    can_tx[6] = 0x00;
    can_tx[7] = 0x00;
    canTransmit(0x1806F4F5, 8U, can_tx);
    status8 = false;
    can_rx_receive_flag = false;
    /******wait for ok ********/
    waitForNextCANMsg();
    /********************************/
    if ((status8 != true) || (can_data8[0] != 0x01)) {
        uart_transmit(timeout_msg);
        canTransmit(0x1806F4F6, 8U, can_timeOut);
        return;
    }

    /********All params sent, acknwoledge GUI****/
    uart_transmit(gui_ack);
    status8 = false;
    can_rx_receive_flag = false;


}


void waitForNextCANMsg() {
    can_rx_receive_flag = false;
    timeout2 = false;
    TMR2_Start();
    do {

        if (timeout2 == true) {
            uart_transmit(timeout_msg);
            canTransmit(0x1806F4F6, 8U, can_timeOut);
            timeout2 = false;
            break;

        }

    } while (can_rx_receive_flag != true);
    TMR2_Stop();


}
void waitForNextGUIMsg(){
    rx_receive_complete = false;
    timeout0 = false;
    TMR0_StartTimer();
    do{
        
        if (timeout0 == true) {
            uart_transmit(timeout_msg);
            canTransmit(0x1806F4F6, 8U, can_timeOut);
            timeout0 = false;
            break;

        }
        
        
        
    }while(rx_receive_complete != true);
     TMR0_StopTimer();
    
}



void sd_data_flow() {

    //flow control
    uint8_t  can_rx_sd_index, i;
    waitForNextCANMsg();
    if (status10 != true) {
        uart_transmit(timeout_msg);
        canTransmit(0x1806F4F6, 8U, can_timeOut);
        return;
    }

label1:
    switch (can_data10[0]) {
        case 0x10: //6 bytes
            can_rx_sd_index = 0;
            for (i = 1; i < 8; i++) {
                if (i == 1) {
                    can_rx_sd_byte = can_data10[i];
                } else {
                    can_rx_sd[can_rx_sd_index] = can_data10[i];
                    can_rx_sd_index++;
                }
            }

            canTransmit(0x1806F4F6, 4U, can_ack);
            status10 = false;
            can_rx_receive_flag = false;
            break;

        case 0x20: //6+7 bytes
            can_rx_sd_index = 6;
            for (i = 1; i < 8; i++) {
                can_rx_sd[can_rx_sd_index] = can_data10[i];
                can_rx_sd_index++;
            }
            canTransmit(0x1806F4F6, 4U, can_ack);
            status10 = false;
            can_rx_receive_flag = false;
            break;

        case 0x21: //6+7+7 bytes
            can_rx_sd_index = 13;
            for (i = 1; i < 8; i++) {
                can_rx_sd[can_rx_sd_index] = can_data10[i];
                can_rx_sd_index++;
            }
            canTransmit(0x1806F4F6, 4U, can_ack);
            status10 = false;
            can_rx_receive_flag = false;
            break;

        case 0x22: //6+7+7+7 bytes
            can_rx_sd_index = 20;
            for (i = 1; i < 8; i++) {
                can_rx_sd[can_rx_sd_index] = can_data10[i];
                can_rx_sd_index++;
            }
            canTransmit(0x1806F4F6, 4U, can_ack);
            status10 = false;
            can_rx_receive_flag = false;
            break;

        case 0x23://6+7+7+7+7 bytes
            can_rx_sd_index = 27;
            for (i = 1; i < 8; i++) {
                can_rx_sd[can_rx_sd_index] = can_data10[i];
                can_rx_sd_index++;
            }
            canTransmit(0x1806F4F6, 4U, can_ack);
            status10 = false;
            can_rx_receive_flag = false;
            break;

        case 0x24://6+7+7+7+7+7 bytes
            can_rx_sd_index = 34;
            for (i = 1; i < 8; i++) {
                can_rx_sd[can_rx_sd_index] = can_data10[i];
                can_rx_sd_index++;
            }
            canTransmit(0x1806F4F6, 4U, can_ack);
            status10 = false;
            can_rx_receive_flag = false;
            break;
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
